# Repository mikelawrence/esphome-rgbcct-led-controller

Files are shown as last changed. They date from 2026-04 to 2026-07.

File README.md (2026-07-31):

# ESPHome RGBCCT LED Controller

<p align="center">
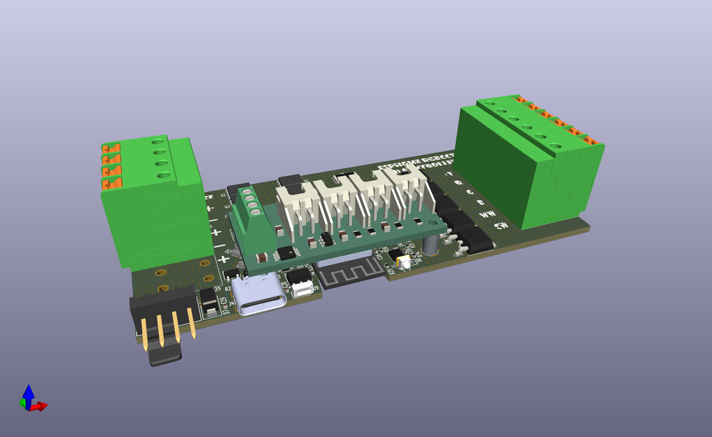
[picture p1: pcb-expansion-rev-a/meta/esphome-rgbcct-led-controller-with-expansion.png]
  
</p>

This project evolved from the need to support LED strips for growing African Violets. It is surprising how much light plants need and how little light LED strip actually put out. My original approach was three strips composed of Cool White (CW) and Warm White LEDs (WW). But it wasn't until I purchased a Photosynthetically Active Radiation (PAR) meter to measure the Photosynthetic Photon Flux Density (PPFD, units µmol/m²/s) just how un-bright my setup was. These units are interesting. The first part, µmol, is a number, specifically one-millionth of a mole, or 6.022 x 10²³ / 1,000,000 or 6.022 x 10¹⁷. The second part is an area, 1 meter squared. And finally time in seconds. When put together it is basically the number of photons striking a one meter squared area per second. Most measurements of light intensity, like lux, lumens, or luminance, are based on human perception are not really good for plants so PAR/PPFD was developed in the 1970s by Dr. Keith McCree. When I measured the light output of my setup with my shiny new PAR meter I got 20PPFD with my original setup of three strips of CW and WW LEDs between 60 and 200PPFD. There is different and sometimes conflicting information on the Internet but the range I found for African Violets is somewhere between 60 and 200PPFD. So my setup was three times less than minimum of 60PPFD.

Clearly I need more light. I started looking on Internet for "brighter" LED strips. I found [these](https://www.superlightingled.com/dc24v-112ledsm-highest-density-5in1-rgbww-led-strip-smd5050-164ft-p-5599.html) from SUPERLIGHTINGLED they have 5 different LEDS, Red, Green, Blue, Warm White and Cool Light. This is five PWM channels which reduces the available controllers to only a few but I did find a Zigbee 5-channel controller. But the control of the LEDs are difficult. What I really needed was to turn on all LEDS simultaneously and this controller could not so this with Home Assistant. It also adjust the light intensity with gamma which again is based on human perception. I found another controller from GLEDOPTO with WLED installed which gave me chance to control everything in the way I wanted and that is when I realized turning all the LEDS on at the same time caused them to warm up to more than 50°C. Not necessarily a problem but one that would probably shorten the life of the strips. I ended up with five of these LED strips per shelf running at a reduced intensity and still have 80PPFD.

Now that the light levels are in better range I decided to design my own LED controller because I wanted to add 4-Pin computer fan control and temperature measurement of both ambient and some of the LED strips to make sure I wasn't getting them too hot.

This LED controller supports the following:

* ESP32-S3
* ESPHome software development
* USB-C Interface for initial/ongoing programming, OTA will still be the primary mean of programming
* Power, Voltage and Current measurement with an INA232
* 5-Channel PWM LED control
* Supporting 5-24V Vin, this same voltage is applied to the LED and fan
* Two configurations: One supporting 5A and with the addition of two transistors 10A total current
* Each channel comfortably supports 2A simultaneous and up to 3-4A singly
* Vin is well protected
  * No damage input range is ±33V, TVS will adsorb higher transients
  * Over current shutdown
  * Over temperature shutdown
  * Short circuit shutdown
  * Reverse Polarity shutdown
  * Over Voltage Lockout
  * Under Voltage Lockout
* PCB temperature measurement near the Vin protection circuit. This is broken.
* Each channel is a protected MOSFET, if will shutdown when over temperature and will take a short to ground without damage
* With the addition of an expansion board
  * LED strip temperature measurement with 10K thermistors.
  * Ambient temperature measurement with a commonly available SHTXX I²C sensor

## Main PCB

<p align="center">
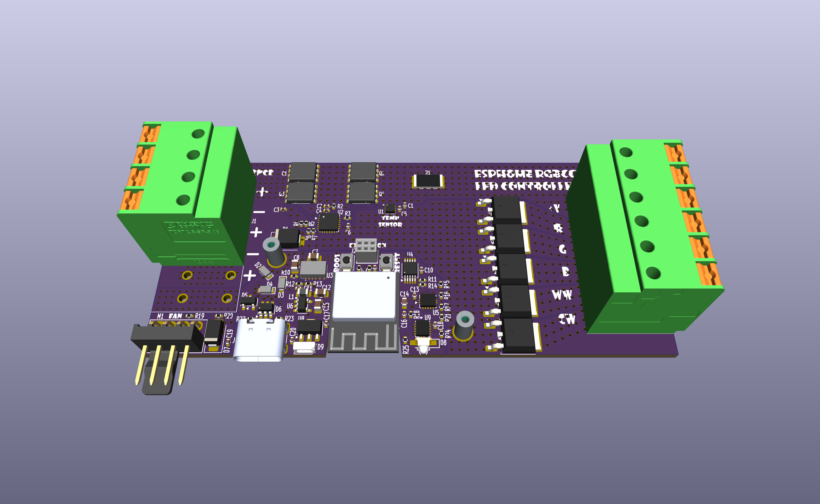
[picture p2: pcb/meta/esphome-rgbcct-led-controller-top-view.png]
  
</p>

View the [README](pcb/README.md) for more information about this PCB.

## Temperature Expansion PCBs

<p align="center">
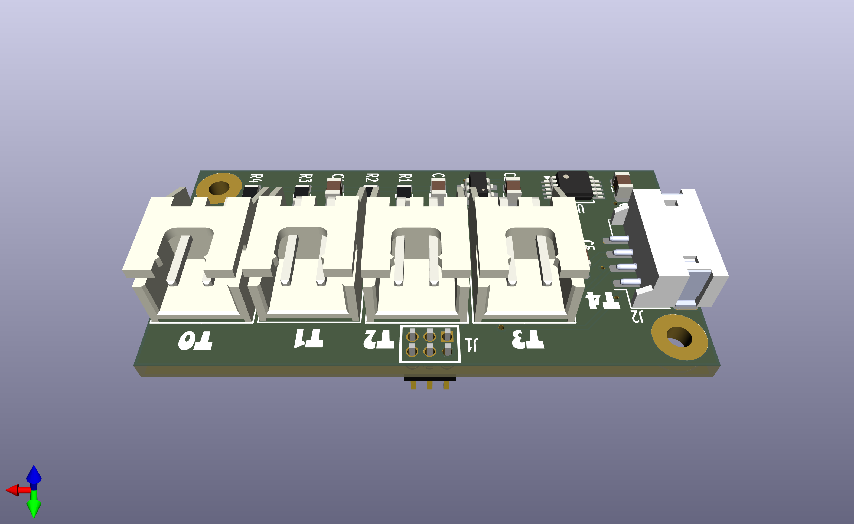
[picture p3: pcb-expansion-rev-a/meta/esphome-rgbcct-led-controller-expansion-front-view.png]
    
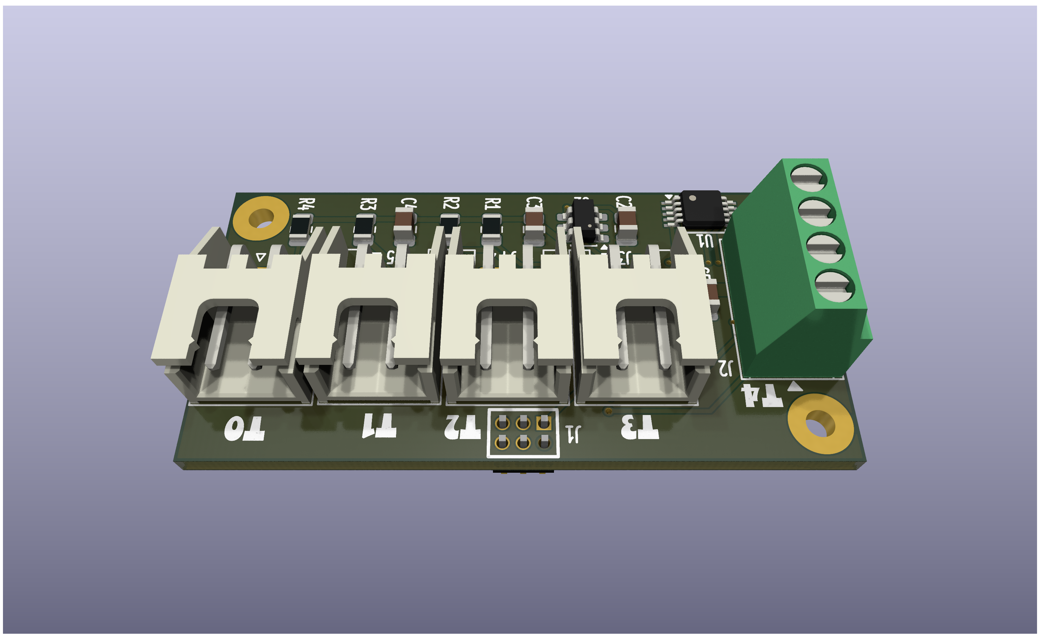
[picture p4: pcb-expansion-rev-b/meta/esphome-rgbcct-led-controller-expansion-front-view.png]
    
</p>

View the [Rev A README](pcb-expansion-rev-a/README.md) or [Rev B README](pcb-expansion-rev-b/README.md) for more information.

## Configuration

[RGBCCT LED Controller GH Pages](https://mikelawrence.github.io/esphome-rgbcct-led-controller/) provides installation and Home Assistant configuration support.

## Web Server

Th Web Server is enabled in the current configuration. The default username is `light` and password is `password`. Auth is enabled mainly because manual firmware updates are enabled in the Web Server.

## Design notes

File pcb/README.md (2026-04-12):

# ESPHome RGBCCT LED Controller PCB

<p align="center">
  
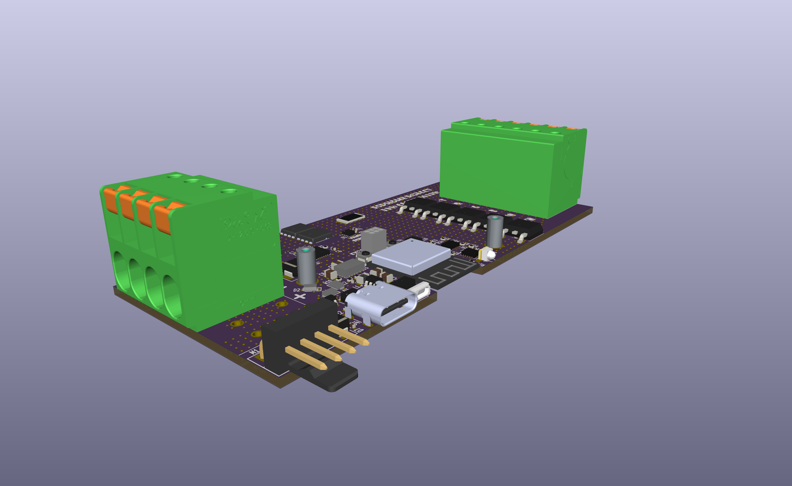
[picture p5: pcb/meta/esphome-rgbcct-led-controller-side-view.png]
  
</p>

The PCB is designed in [KiCad](https://www.kicad.org/). Fabrication and is tuned toward [JCLPCB](https://jlcpcb.com/). I using my [Whizoo Controleo3](https://whizoo.com/) oven to handle all but the Thru-Hole stuff which is hand soldered.

* **Rev A**: Has been fabricated, assembled, tested and is use in four places. There is one issue TMP1075 (U1) is connected to VINP and will burn when powered by 24V and must be left off the PCB.

## Testing Notes

Only the 5A configuration has been tested. Short circuit on LED outputs will not damage the board but the red LED will not light up. This type of short circuits will recover automatically recover when removed. Short circuits on the fan connector will shut off power to everything and cause the red LED to light up. Short circuits of this type are latching and require power-cycling to release. Over-voltage and Under-Voltage Lock Out work fine. The 4-Pin fan connector supports fans but the PWM signal is 1.5kHz well below the recommended 25kHz. There seems to be an issue with the ledc component the prevents different pwm frequencies when using 6 ledc channels. 1.5kHz work well with Noctua fans.

## Schematic

<p align="center">
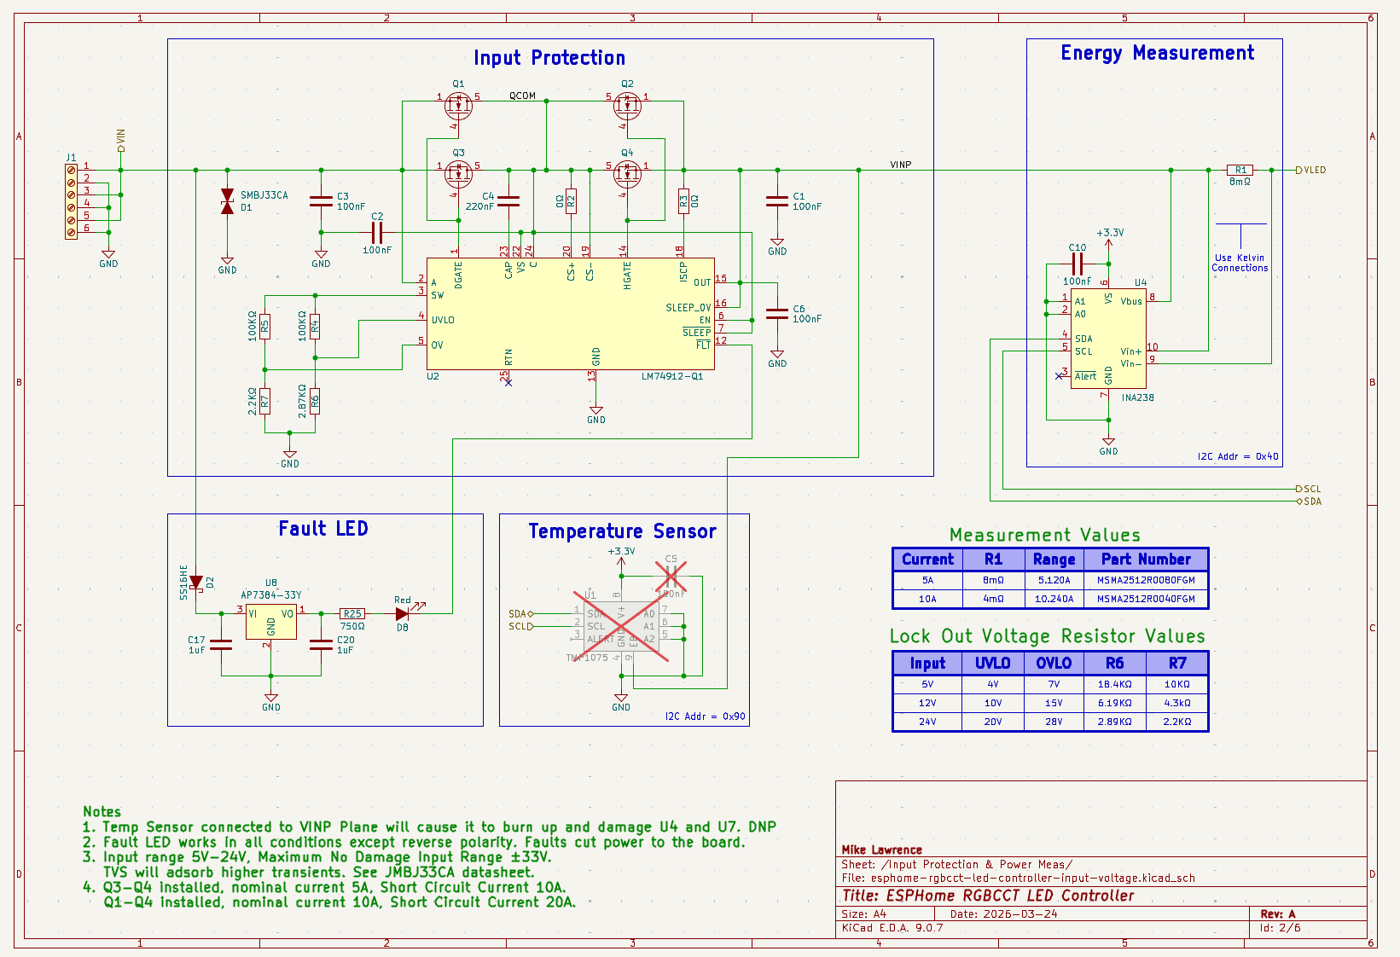
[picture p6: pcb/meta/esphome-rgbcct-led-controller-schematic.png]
     <br />
    Schematic
</p>

### Do Not Populate (DNP) Notes

TMP1075 (U1) cannot be populated due to a PCB error. It will burn with 24V Vin.

## Bill of Materials

<p align="center">
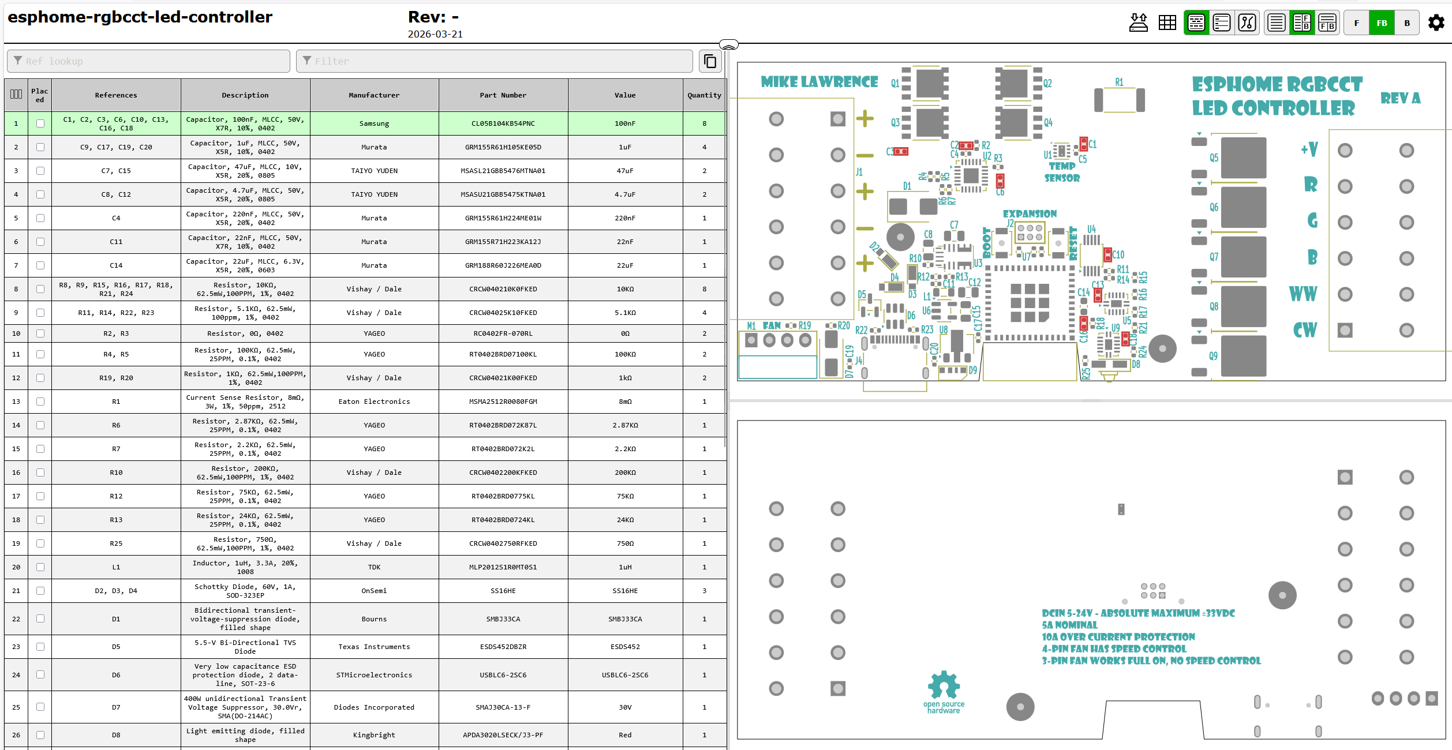
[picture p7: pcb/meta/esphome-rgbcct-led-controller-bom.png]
     <br />
    Interactive BOM
</p>

## PCB Info

* 6 layers with many vias to support high currents. Vias should be filled to improve thermals.
* Two configurations, 5A Continuous, 10A Short Circuit and 10A Continuous and 20A Short Circuit.
* Dimensions are 100mm X 45mm.
* Requires oven reflow or hot air to assemble most components.

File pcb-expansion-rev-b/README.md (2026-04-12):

## ESPHome RGBCCT LED Controller Temperature Expansion PCB Rev B

<p align="center">
  
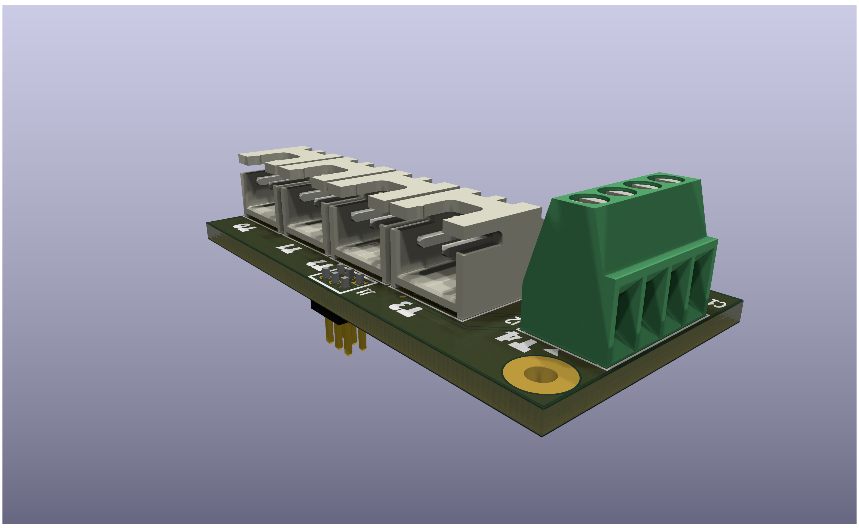
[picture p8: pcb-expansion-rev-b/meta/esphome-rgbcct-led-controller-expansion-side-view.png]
  
</p>

This is a simple expansion board used to add both thermistor measurement and i2c expansion, mainly for off-board temperature and humidity sensors like SHTxxx devices. Rev B has a screw terminal for the off-board i2c temperature/humidity sensor. This PCB is designed in [KiCad](https://www.kicad.org/). Fabrication and is tuned toward [JCLPCB](https://jlcpcb.com/). 100% hand-soldered.

* **Rev B**: Has has not been fabricated nor tested.

## Schematic

<p align="center">
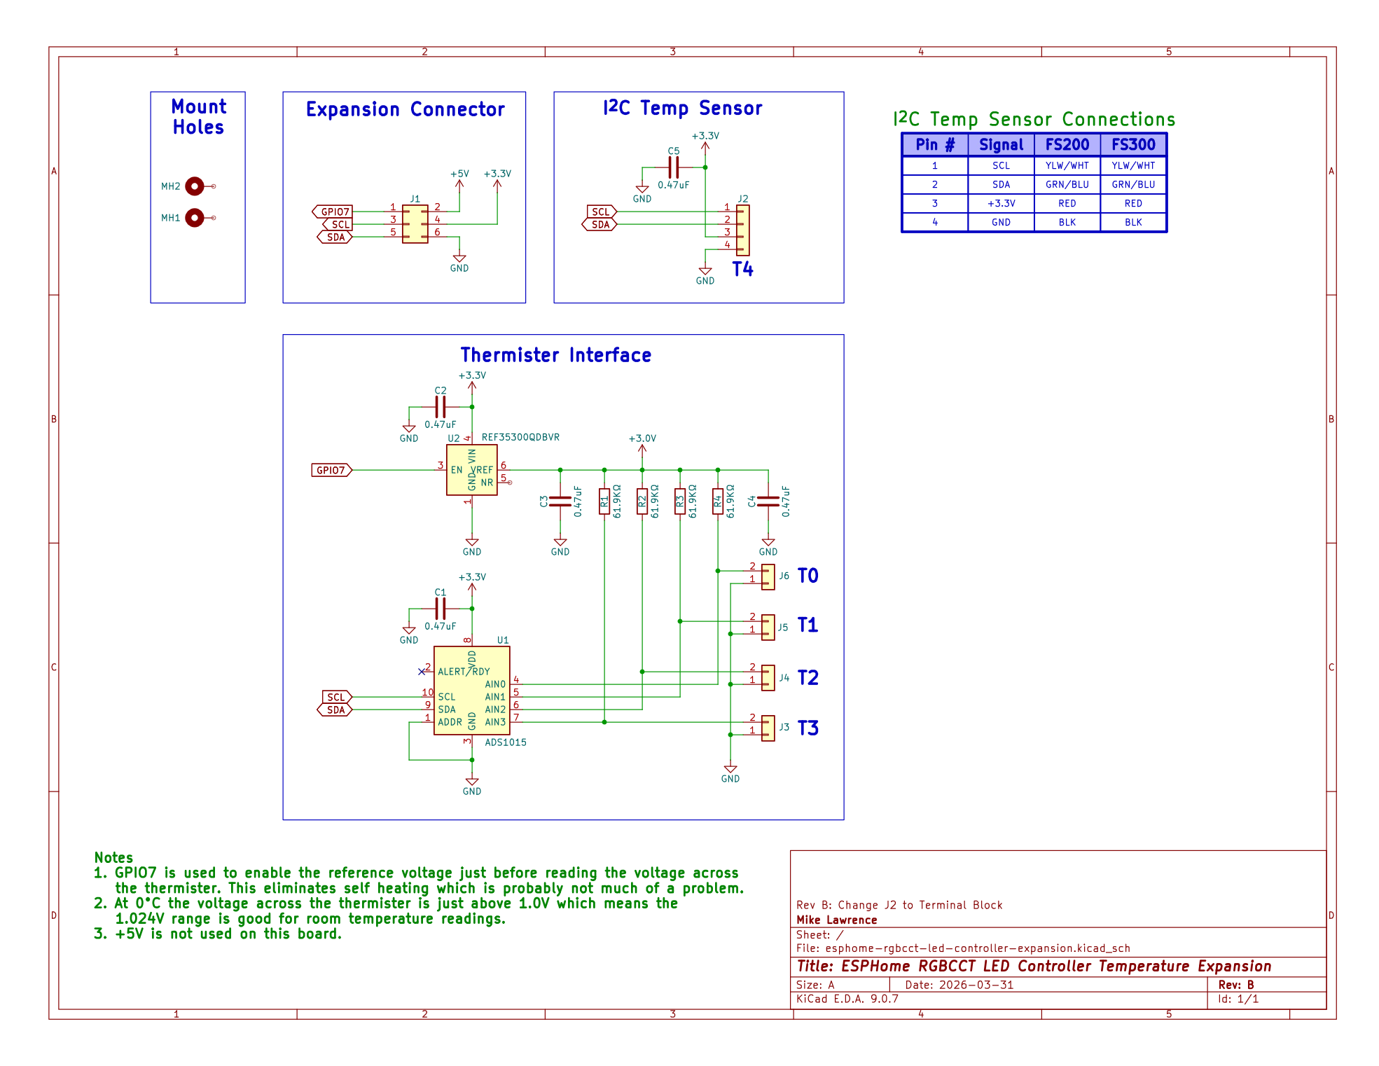
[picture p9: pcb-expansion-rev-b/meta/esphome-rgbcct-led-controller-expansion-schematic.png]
     <br />
    Schematic
</p>

## Bill of Materials

<p align="center">
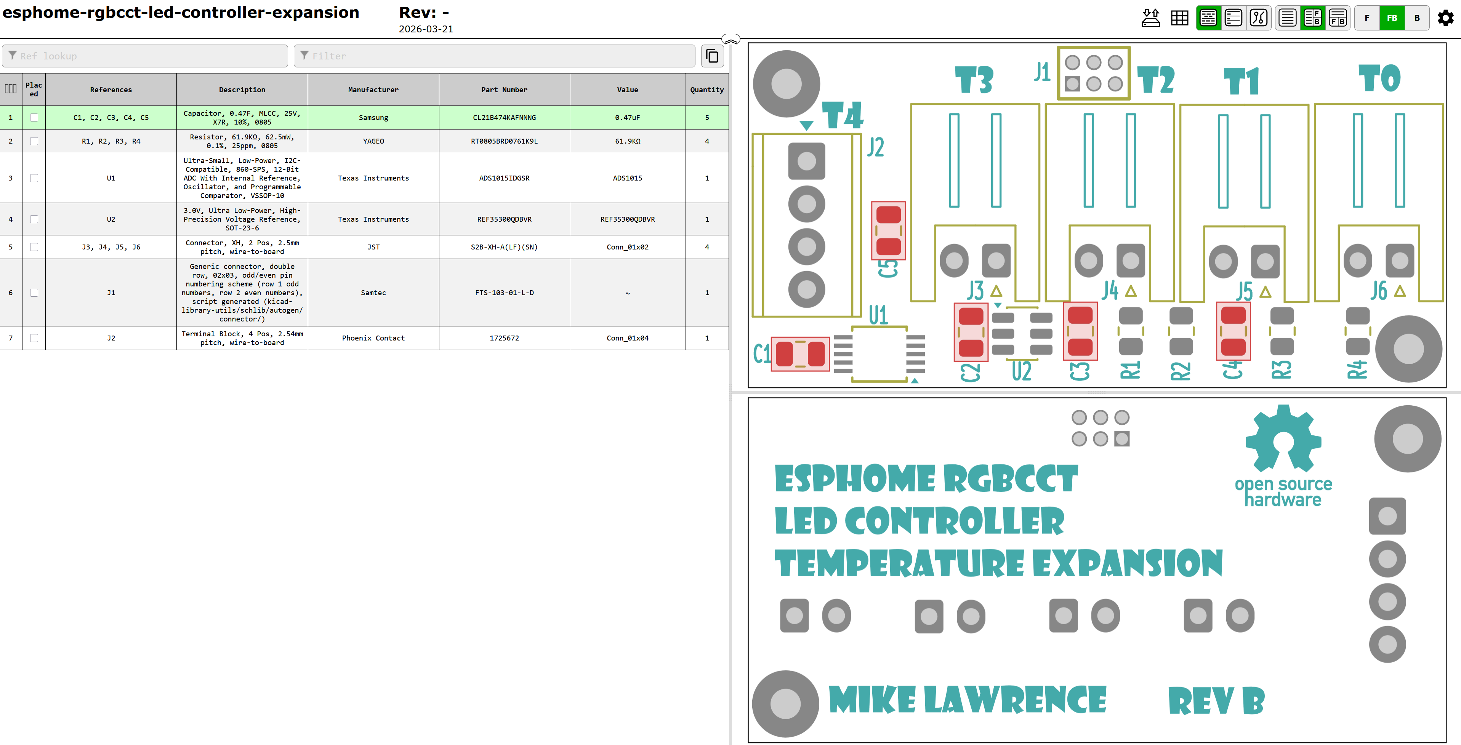
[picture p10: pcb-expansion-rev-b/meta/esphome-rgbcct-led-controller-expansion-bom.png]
     <br />
    Interactive BOM
</p>

## PCB Info

* 2 layers, simple inexpensive PCB.
* Intended for hand-soldering.

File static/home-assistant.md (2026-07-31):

---
description: Using the Multi-Sensor in Home Assistant
---

Sensor

# Home Assistant

There are numerous entities presented to Home Assistant here is a complete list of each with a description.

## Controls

- **Fan** (*Fan*): Provides Fan control in percentage. This is the offboard muffin fan used to circulate air.

- **Light** (*RGBWW Light*): Light control for the LED light strips connected to the controller. Supports 5 channels of PWM for Red, Green, Blue, Warm White and Cool White LED channels.

## Sensors

- **Current** (*Sensor*): This measures the current (A) the entire unit is using including LED lights strips. Updates every minute.

- **Energy** (*Sensor*): This measures the accumulated energy (W Hr) the entire unit has used including LED lights strips. Updates every minute. Resets ant midnight.

- **Fan RPM** (*Sensor*): Current Fan RPM reading. Updates every minute.

- **Humidity** (*Sensor*): Current Humidity sensor reading from the offboard temperature sensor stalk. This is part of a SHT3X sensor. Updates every minute.

- **LED Blue** (*Sensor*): This is the current Blue LED channel intensity in percentage. Updates every change of RGBWW light. Not enabled by default.

- **LED Green** (*Sensor*): This is the current Blue LED channel intensity in percentage. Updates every change of RGBWW light. Not enabled by default.

- **LED Red** (*Sensor*): This is the current Blue LED channel intensity in percentage. Updates every change of RGBWW light. Not enabled by default.

- **LED White Cool** (*Sensor*): This is the current Cool White LED channel intensity in percentage. Updates every change of RGBWW light. Not enabled by default.

- **LED White Warm** (*Sensor*): This is the current Warm White LED channel intensity in percentage. Updates every change of RGBWW light. Not enabled by default.

- **Power** (*Sensor*): This measures the current (A) the entire unit is using including LED lights strips. Updates every minute.

- **Temperature** (*Sensor*): Current Temperature sensor reading from the offboard temperature sensor stalk. This is part of a SHT3X sensor. Updates every minute.

- **Voltage** (*Sensor*): This measures the voltage (V) applied to the unit. Updates every minute.

## Configuration

- **Max Power** (*Number*): Provide the means to limit the total power the RGBWW Light. In some cases a LED Light strip with 5 channels of LED control will
get too hot if all channels are on. By lowering this number from 100% you can effectively limit the total output power. The following equation is used to
determine the brightness level of the RGBWW light.

Brightness = 100 * (RLED(%) + GLED(%) + BLED(%) + WWLED(%) + CW(%)) / (RLED(100%) + GLED(100%) + BLED(100%) + WWLED(100%) + CW(100%))

Adjusting brightness will keep the light color consistent for the most part.

- **Restart** (*Button*): Will restart RGBCCT LED Controller

[back](./)

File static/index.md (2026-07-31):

Sensor

# Web Installation

Use the button below to install pre-built firmware directly to your hardware via USB. You must use Google Chrome or Microsoft Edge to program your device. Firefox does not work.

| &nbsp; &nbsp; &nbsp; &nbsp; &nbsp; 5A Nominal 10A Short &nbsp; &nbsp; &nbsp; &nbsp; &nbsp; | &nbsp; &nbsp; &nbsp; &nbsp; &nbsp; 10A Nominal 20A Short &nbsp; &nbsp; &nbsp; &nbsp; &nbsp; |
| :---: | :---: |
| <esp-web-install-button manifest="firmware/rgbcct-led-controller-5amp.manifest.json"></esp-web-install-button> | <esp-web-install-button manifest="firmware/rgbcct-led-controller-10amp.manifest.json"></esp-web-install-button> |

<script type="module" src="https://unpkg.com/esp-web-tools@10/dist/web/install-button.js?module"></script>

# Configuration Notes

Click [Home Assistant configuration page](./home-assistant.html) to learn what's available in Home Assistant.

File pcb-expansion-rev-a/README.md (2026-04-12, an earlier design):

## ESPHome RGBCCT LED Controller Temperature Expansion PCB Rev A

<p align="center">
  
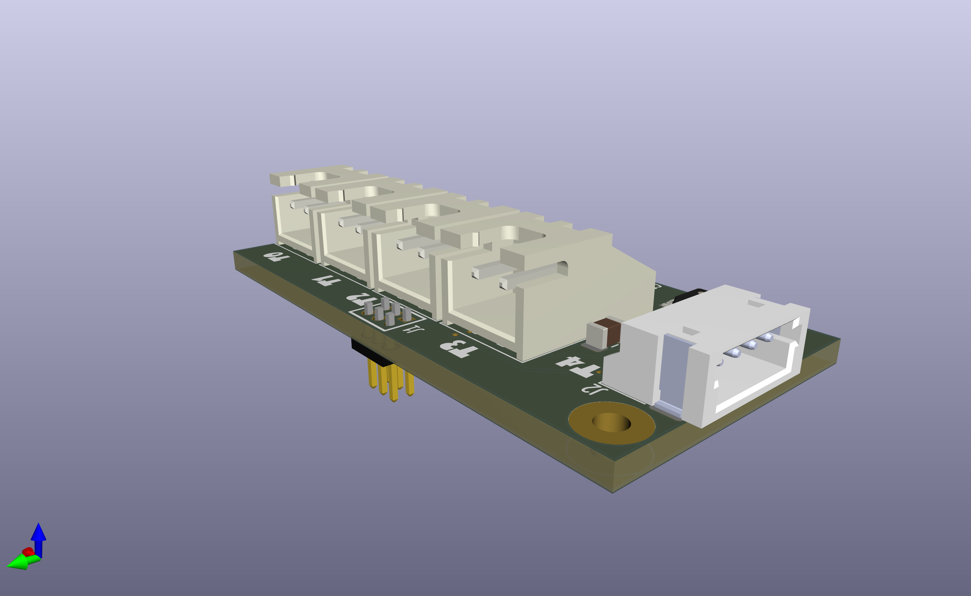
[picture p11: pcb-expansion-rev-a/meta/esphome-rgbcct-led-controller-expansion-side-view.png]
  
</p>

This is a simple expansion board used to add both thermistor measurement and i2c expansion, mainly for off-board temperature and humidity sensors like SHTxxx devices. Rev A has a JST ZR connector for the off-board i2c temperature/humidity sensor. This PCB is also designed in [KiCad](https://www.kicad.org/). Fabrication and is again tuned toward [JCLPCB](https://jlcpcb.com/). 100% hand-soldered.

* **Rev A**: Has has fabricated, assembled and tested. No issues.

## Schematic

<p align="center">
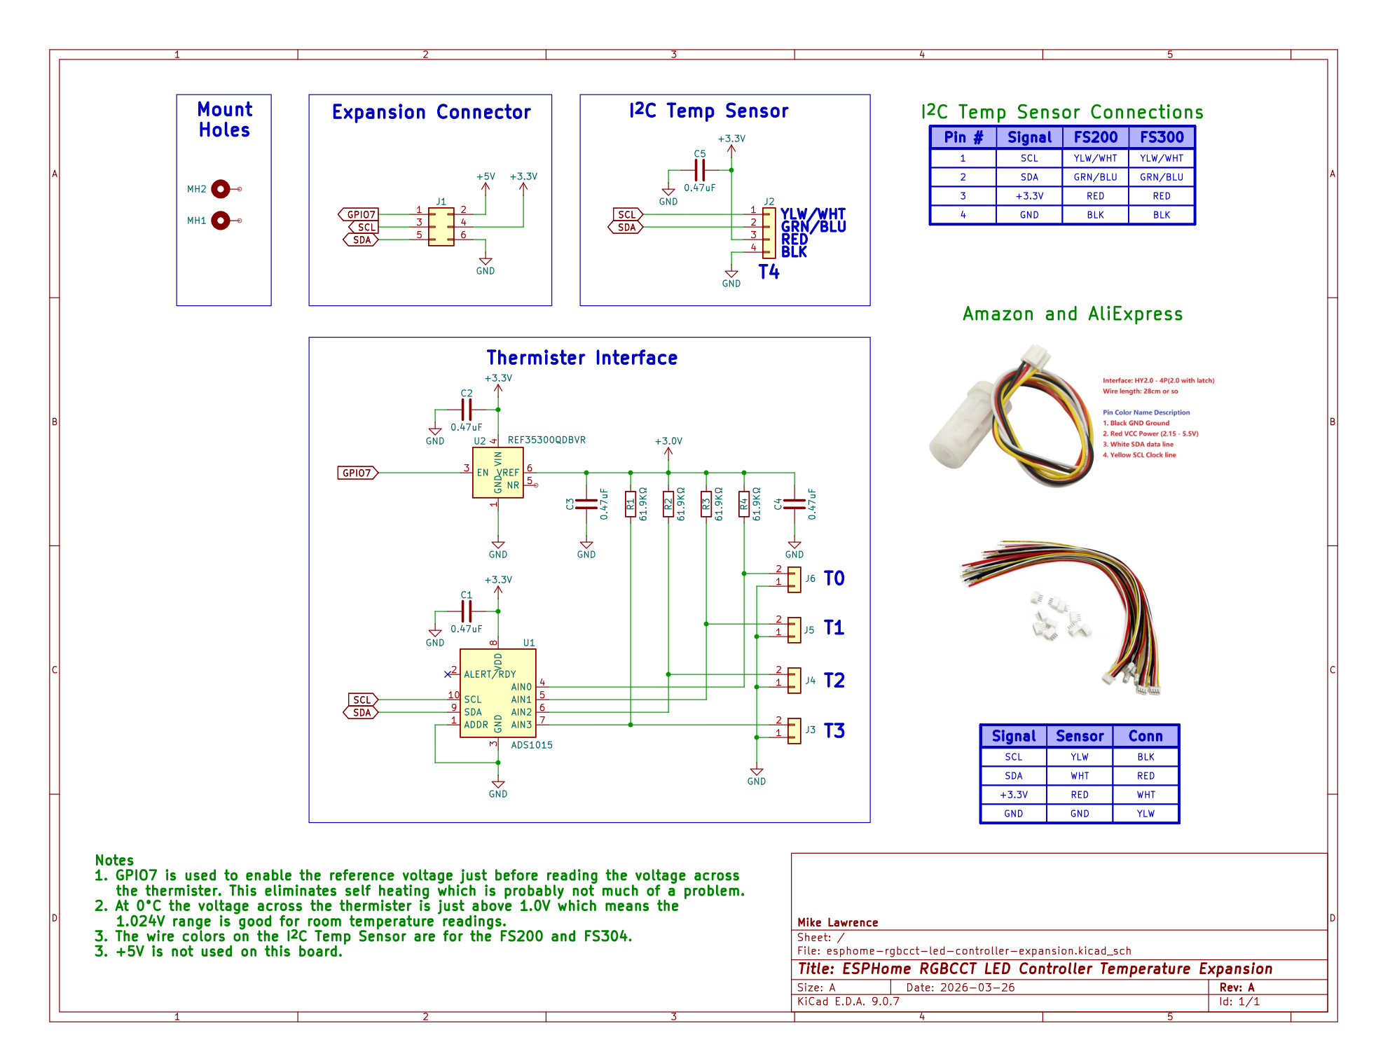
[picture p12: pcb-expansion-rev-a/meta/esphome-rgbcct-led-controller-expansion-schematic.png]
     <br />
    Schematic
</p>

## Bill of Materials

<p align="center">
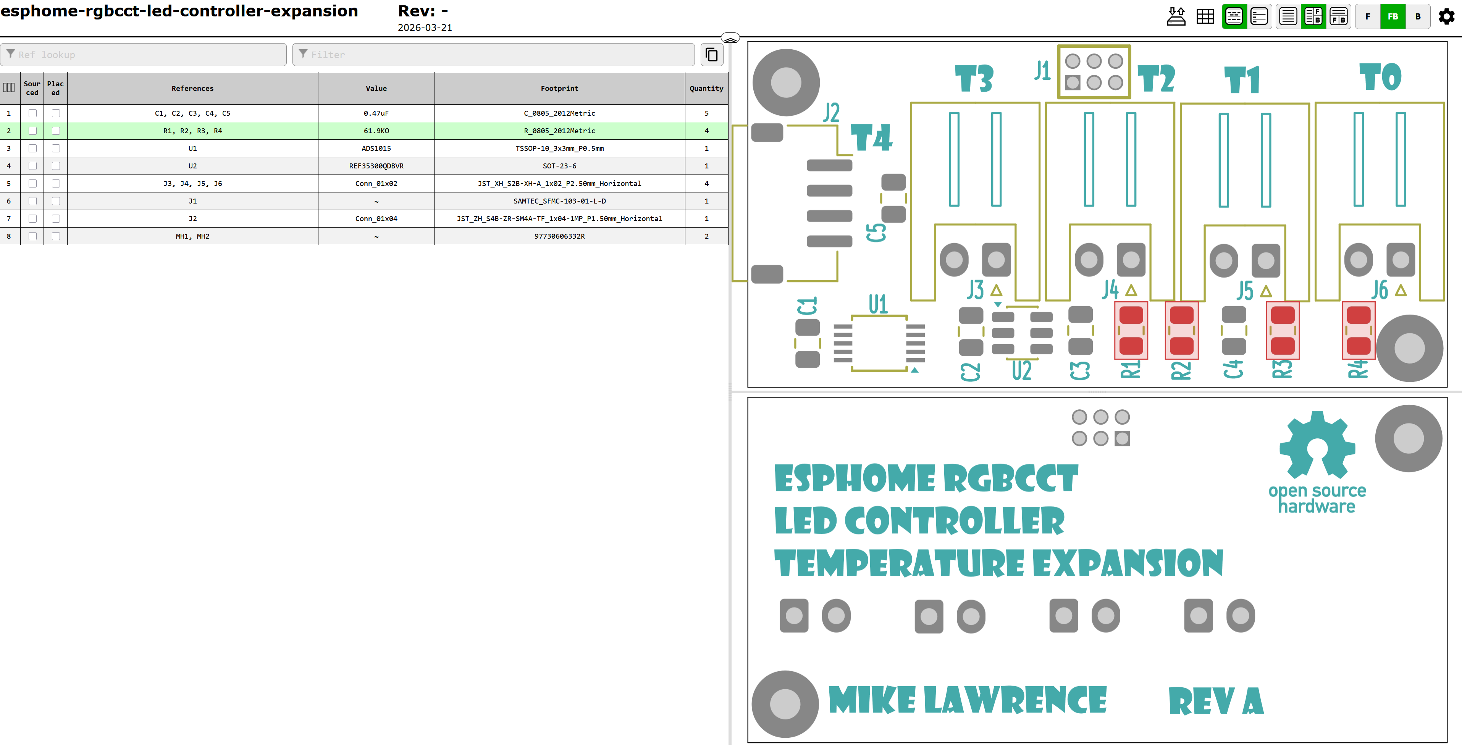
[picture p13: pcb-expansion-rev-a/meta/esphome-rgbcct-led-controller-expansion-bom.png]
     <br />
    Interactive BOM
</p>

## PCB Info

* 2 layers, simple inexpensive PCB.
* Intended for hand-soldering.

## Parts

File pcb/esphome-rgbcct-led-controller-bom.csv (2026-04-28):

Qty | Reference | Value | Description | Datasheet | Footprint | DNP | Manufacturer | Part Number
9 | C1,C2,C3,C5,C6,C10,C13,C16,C18 | 100nF | Capacitor, 100nF, MLCC, 50V, X7R, 10%, 0402 |  | Capacitor_SMD:C_0402_1005Metric | DNP | Samsung | CL05B104KB54PNC
1 | C4 | 220nF | Capacitor, 220nF, MLCC, 50V, X5R, 20%, 0402 |  | Capacitor_SMD:C_0402_1005Metric |  | Murata | GRM155R61H224ME01W
2 | C7,C15 | 47uF | Capacitor, 47uF, MLCC, 10V, X5R, 20%, 0805 |  | Capacitor_SMD:C_0805_2012Metric |  | TAIYO YUDEN | MSASL21GBB5476MTNA01
2 | C8,C12 | 4.7uF | Capacitor, 4.7uF, MLCC, 50V, X5R, 20%, 0805 |  | Capacitor_SMD:C_0805_2012Metric |  | TAIYO YUDEN | MSASU21GBB5475KTNA01
4 | C9,C17,C19,C20 | 1uF | Capacitor, 1uF, MLCC, 50V, X5R, 10%, 0402 |  | Capacitor_SMD:C_0402_1005Metric |  | Murata | GRM155R61H105KE05D
1 | C11 | 22nF | Capacitor, 22nF, MLCC, 50V, X7R, 10%, 0402 |  | Capacitor_SMD:C_0402_1005Metric |  | Murata | GRM155R71H223KA12J
1 | C14 | 22uF | Capacitor, 22uF, MLCC, 6.3V, X5R, 20%, 0603 |  | Capacitor_SMD:C_0603_1608Metric |  | Murata | GRM188R60J226MEA0D
1 | D1 | SMBJ33CA | Bidirectional transient-voltage-suppression diode, filled shape |  | Diode_SMD:D_SMB |  | Bourns | SMBJ33CA
3 | D2,D3,D4 | SS16HE | Schottky Diode, 60V, 1A, SOD-323EP | https://www.onsemi.com/pdf/datasheet/ss13he-d.pdf | SS16HE:SS16HE |  | OnSemi | SS16HE
1 | D5 | ESDS452 | 5.5-V Bi-Directional TVS Diode | https://www.ti.com/lit/ds/symlink/esds452.pdf | Package_TO_SOT_SMD:SOT-23 |  | Texas Instruments | ESDS452DBZR
1 | D6 | USBLC6-2SC6 | Very low capacitance ESD protection diode, 2 data-line, SOT-23-6 | https://www.st.com/resource/en/datasheet/usblc6-2.pdf | Package_TO_SOT_SMD:SOT-23-6 |  | STMicroelectronics | USBLC6-2SC6
1 | D7 | 30V | 400W unidirectional Transient Voltage Suppressor, 30.0Vr, SMA(DO-214AC) | https://www.littelfuse.com/media?itemid=75e32973-b177-4ee3-a0ff-cedaf1abdb93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 | Diode_SMD:D_SMA |  | Diodes Incorporated | SMAJ30CA-13-F
1 | D8 | Red | Light emitting diode, filled shape | https://www.kingbrightusa.com/images/catalog/SPEC/APDA3020LSECK-J3-PF.pdf | APDA3020LSECK_J3-PF:APDA3020LSECKJ3PF |  | Kingbright | APDA3020LSECK/J3-PF
1 | D9 | SK6812-4020 | RGB LED with integrated controller, 4mm x 2mm Side LED package | https://cdn-shop.adafruit.com/product-files/4691/4691_SK68XX_SIDE_REV.04_EN_1_.pdf | SK6812-4020:SK6812-4020 |  | Adafruit | 4691
1 | J1 | 1017505 | Terminal Block, 12-24 AWG, push-in connection, 4-position, 32A | https://www.mouser.com/datasheet/3/507/10/phoenix_contact_1017507_en.pdf | 1017507:1017507 |  | Phoenix Contact | 1017505
1 | J2 |  | Generic connector, double row, 02x03, odd/even pin numbering scheme (row 1 odd numbers, row 2 even numbers), script generated (kicad-library-utils/schlib/autogen/connector/) |  | SAMTEC_SFMC10301LD:SAMTEC_SFMC-103-01-L-D |  | Samtec | SFMC-103-01-L-D
1 | J3 | 1017507 | Terminal Block, 12-24 AWG, push-in connection, 6-position, 32A | https://www.mouser.com/datasheet/3/507/10/phoenix_contact_1017507_en.pdf | 1017507:1017507 |  | Phoenix Contact | 1017507
1 | J4 | USB-C | Connector, USB 2.0, 16P, Type-C, Receptacle | https://www.usb.org/sites/default/files/documents/usb_type-c.zip | TYPE-C-31-M-12:HRO_TYPE-C-31-M-12 |  | Phoenix Contact | 1332645
1 | L1 | 1uH | Inductor, 1uH, 3.3A, 20%, 1008 |  | Inductor_SMD:L_0805_2012Metric |  | TDK | MLP2012S1R0MT0S1
1 | M1 | Fan_CPU_4pin | CPU Fan, tacho output, PWM input, 4-pin connector | http://www.formfactors.org/developer%5Cspecs%5Crev1_2_public.pdf | Connector:FanPinHeader_1x04_P2.54mm_Vertical |  | Molex | 47053-1000
2 | MH1,MH2 |  | Mounting Hole with connection | https://www.we-online.com/components/products/datasheet/97730606332R.pdf | 97730606332R:97730606332R |  | Wurth | 97730606332R
4 | Q1,Q2,Q3,Q4 | TQM050NB06CR | N-MOSFET transistor, 60V, 104A, 5mΩ, 3.8V Vgs, PDFN56U | https://services.taiwansemi.com/storage/resources/datasheet/TQM050NB06CR_A2003.pdf | TQM050NB06CR_RLG:TRANS_TQM050NB06CR_RLG |  | Taiwan Semiconductor | TQM050NB06CR RLG
5 | Q5,Q6,Q7,Q8,Q9 | NCV8411 | Self-Protected Low Side Driver with Temperature and Current Limit, TO-252-2 | https://www.onsemi.com/pdf/datasheet/ncv8411-d.pdf | Package_TO_SOT_SMD:TO-252-2 |  | OnSemi | NCV8411DTRKG
1 | R1 | 8mΩ | Current Sense Resistor, 8mΩ, 3W, 1%, 50ppm, 2512 |  | Resistor_SMD:R_2512_6332Metric |  | Eaton Electronics | MSMA2512R0080FGM
2 | R2,R3 | 0Ω | Resistor, 0Ω, 0402 |  | Resistor_SMD:R_0402_1005Metric |  | YAGEO | RC0402FR-070RL
2 | R4,R5 | 100KΩ | Resistor, 100KΩ, 62.5mW, 25PPM, 0.1%, 0402 |  | Resistor_SMD:R_0402_1005Metric |  | YAGEO | RT0402BRD07100KL
1 | R6 | 2.87KΩ | Resistor, 2.87KΩ, 62.5mW, 25PPM, 0.1%, 0402 |  | Resistor_SMD:R_0402_1005Metric |  | YAGEO | RT0402BRD072K87L
1 | R7 | 2.2KΩ | Resistor, 2.2KΩ, 62.5mW, 25PPM, 0.1%, 0402 |  | Resistor_SMD:R_0402_1005Metric |  | YAGEO | RT0402BRD072K2L
8 | R8,R9,R15,R16,R17,R18,R21,R24 | 10KΩ | Resistor, 10KΩ, 62.5mW,100PPM, 1%, 0402 |  | Resistor_SMD:R_0402_1005Metric |  | Vishay / Dale | CRCW040210K0FKED
1 | R10 | 200KΩ | Resistor, 200KΩ, 62.5mW,100PPM, 1%, 0402 |  | Resistor_SMD:R_0402_1005Metric |  | Vishay / Dale | CRCW0402200KFKED
4 | R11,R14,R22,R23 | 5.1KΩ | Resistor, 5.1KΩ, 62.5mW, 100ppm, 1%, 0402 |  | Resistor_SMD:R_0402_1005Metric |  | Vishay / Dale | CRCW04025K10FKED
1 | R12 | 75KΩ | Resistor, 75KΩ, 62.5mW, 25PPM, 0.1%, 0402 |  | Resistor_SMD:R_0402_1005Metric |  | YAGEO | RT0402BRD0775KL
1 | R13 | 24KΩ | Resistor, 24KΩ, 62.5mW, 25PPM, 0.1%, 0402 |  | Resistor_SMD:R_0402_1005Metric |  | YAGEO | RT0402BRD0724KL
2 | R19,R20 | 1kΩ | Resistor, 1KΩ, 62.5mW,100PPM, 1%, 0402 |  | Resistor_SMD:R_0402_1005Metric |  | Vishay / Dale | CRCW04021K00FKED
1 | R25 | 750Ω | Resistor, 750Ω, 62.5mW,100PPM, 1%, 0402 |  | Resistor_SMD:R_0402_1005Metric |  | Vishay / Dale | CRCW0402750RFKED
2 | SW1,SW2 |  | Switch, SMD | https://omronfs.omron.com/en_US/ecb/products/pdf/en-b3u.pdf | Button_Switch_SMD:SW_SPST_B3U-1000P-B |  | Omron | B3U-1000P
1 | U1 | TMP1075 | I2C-bus digital temperature sensor and thermal watchdog, WSON-8 | https://www.ti.com/lit/gpn/tmp1075 | Package_SON:WSON-8-1EP_2x2mm_P0.5mm_EP0.9x1.6mm_ThermalVias | DNP | Texas Instruments | TMP1075DSGR
1 | U2 | LM74912-Q1 | Automotive Ideal Diode Controller With Fault Output and Overvoltage, Undervoltage, and Short Circuit Protection, VQFN-24 | https://www.ti.com/lit/ds/symlink/lm74912-q1.pdf | Package_DFN_QFN:Texas_RGE0024C_VQFN-24-1EP_4x4mm_P0.5mm_EP2.1x2.1mm |  | Texas Instruments | LM74912QRGERQ1
1 | U3 | MPM3506AGQV-P | Switching Voltage Regulators 36V/0.6A Module Sync Step-Down Converter | https://www.monolithicpower.com/pub/media/document/MPM3506A_r1.0.pdf | MPM3506A:QFN-19 |  | Monolithic Power Systems | MPM3506AGQV-P
1 | U4 | INA238 | IC, 85-V, 16-Bit, High-Precision Power Monitor With I2C Interface, VSSOP-10 | https://www.ti.com/lit/ds/symlink/ina238.pdf | Package_SO:VSSOP-10_3x3mm_P0.5mm |  | Texas Instruments | INA238AIDGSR
2 | U5,U9 | 74AHCT32 | Quad 2-input OR | https://www.ti.com/lit/ds/symlink/sn74ahct32.pdf | Package_DFN_QFN:DHWQFN-14-1EP_2.5x3mm_P0.5mm_EP1x1.5mm |  | Texas Instruments | SN74AHCT32BQAR
1 | U6 | TPS613222ADBV | 1.8A Step-Up Converter, 5V Output Voltage, 0.9-5.5V Input Voltage, SOT-23-5 | http://www.ti.com/lit/ds/symlink/tps61322.pdf | Package_TO_SOT_SMD:SOT-23-5 |  | Texas Instruments | TPS613222ADBVR
1 | U7 | ESP32-C3-MINI-1 | RF Module, ESP32-C3 SoC, Wi-Fi 802.11b/g/n, Bluetooth 5, BLE, 32-bit, 3.3V, onboard antenna, SMD | https://documentation.espressif.com/esp32-c3-mini-1_datasheet_en.pdf | ESP32-C3-MINI:ESP32-C3-MINI-1-N4X |  | Espressif Systems | ESP32-C3-MINI-1-N4X
1 | U8 | AP7384-33Y | 50mA Low Dropout Voltage Regulator, Fixed Output 3.3V, Wide Input Voltage Range 40V, SOT-89-3 | https://www.diodes.com/assets/Datasheets/AP7384.pdf | Package_TO_SOT_SMD:SOT-89-3 |  | Diodes Inc | AP7384-33Y-13

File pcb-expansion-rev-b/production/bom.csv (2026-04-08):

Designator | Footprint | Quantity | Value | LCSC Part #
C1, C2, C3, C4, C5 | 0805 | 5 | 0.47uF | C307331
J1 | SAMTEC_SFMC-103-01-L-D | 1 | ~
J2 | TerminalBlock_Phoenix_MPT-0,5-4-2.54_1x04_P2.54mm_Horizontal | 1 | Conn_01x04
J3, J4, J5, J6 | JST_XH_S2B-XH-A_1x02_P2.50mm_Horizontal | 4 | Conn_01x02 | C157931
MH1, MH2 | 97730606332R | 2 | ~
R1, R2, R3, R4 | 0805 | 4 | 61.9KΩ | C136977
U1 | TSSOP-10_3x3mm_P0.5mm | 1 | ADS1015
U2 | SOT-23-6 | 1 | REF35300QDBVR | C6643299

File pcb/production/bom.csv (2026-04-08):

Designator | Footprint | Quantity | Value | LCSC Part #
C1, C10, C13, C16, C18, C2, C3, C5, C6 | 0402 | 9 | 100nF
C11 | 0402 | 1 | 22nF
C12, C8 | 0805 | 2 | 4.7uF
C14 | 0603 | 1 | 22uF
C15, C7 | 0805 | 2 | 47uF
C17, C19, C20, C9 | 0402 | 4 | 1uF
C4 | 0402 | 1 | 220nF
D1 | D_SMB | 1 | SMBJ33CA
D2, D3, D4 | SS16HE | 3 | SS16HE
D5 | SOT-23 | 1 | ESDS452
D6 | SOT-23-6 | 1 | USBLC6-2SC6
D7 | D_SMA | 1 | 30V
D8 | APDA3020LSECKJ3PF | 1 | Red
D9 | SK6812-4020 | 1 | SK6812-4020
J1 | 1017507 | 1 | 1017505
J2 | SAMTEC_SFMC-103-01-L-D | 1 | ~
J3 | 1017507 | 1 | 1017507
J4 | HRO_TYPE-C-31-M-12 | 1 | USB-C
L1 | 0805 | 1 | 1uH
M1 | FanPinHeader_1x04_P2.54mm_Vertical | 1 | Fan_CPU_4pin
MH1, MH2 | 97730606332R | 2 | ~
Q1, Q2, Q3, Q4 | TRANS_TQM050NB06CR_RLG | 4 | TQM050NB06CR
Q5, Q6, Q7, Q8, Q9 | TO-252-2 | 5 | NCV8411
R1 | 2512 | 1 | 8mΩ
R10 | 0402 | 1 | 200KΩ
R11, R14, R22, R23 | 0402 | 4 | 5.1KΩ
R12 | 0402 | 1 | 75KΩ
R13 | 0402 | 1 | 24KΩ
R15, R16, R17, R18, R21, R24, R8, R9 | 0402 | 8 | 10KΩ
R19, R20 | 0402 | 2 | 1kΩ
R2, R3 | 0402 | 2 | 0Ω
R25 | 0402 | 1 | 750Ω
R4, R5 | 0402 | 2 | 100KΩ
R6 | 0402 | 1 | 2.87KΩ
R7 | 0402 | 1 | 2.2KΩ
SW1, SW2 | SW_SPST_B3U-1000P-B | 2 | ~
U1 | WSON-8-1EP_2x2mm_P0.5mm_EP0.9x1.6mm_ThermalVias | 1 | TMP1075
U2 | Texas_RGE0024C_VQFN-24-1EP_4x4mm_P0.5mm_EP2.1x2.1mm | 1 | LM74912-Q1
U3 | QFN-19 | 1 | MPM3506AGQV-P
U4 | VSSOP-10_3x3mm_P0.5mm | 1 | INA238
U5, U9 | DHWQFN-14-1EP_2.5x3mm_P0.5mm_EP1x1.5mm | 2 | 74AHCT32
U6 | SOT-23-5 | 1 | TPS613222ADBV
U7 | ESP32-C3-MINI-1-N4X | 1 | ESP32-C3-MINI-1
U8 | SOT-89-3 | 1 | AP7384-33Y

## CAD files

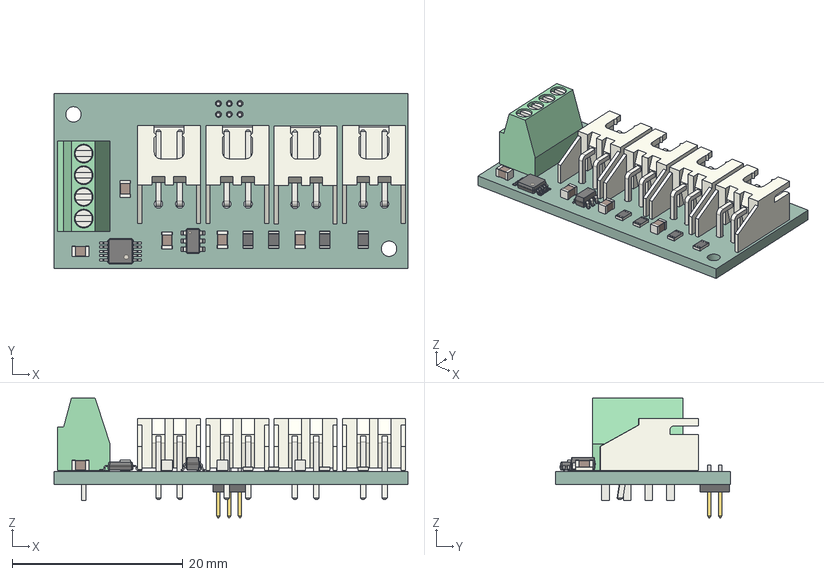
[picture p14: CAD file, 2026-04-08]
pcb-expansion-rev-b/meta/esphome-rgbcct-led-controller-expansion-3d-model.step
41.5 x 20.5 x 14.0 mm
R_0805_2012Metric x 4
JST_XH_S2B-XH-A_1x02_P2.50mm_Horizontal x 4
C_0805_2012Metric x 5
TerminalBlock_Phoenix_MPT-0,5-4-2.54_1x04_P2.54mm_Horizontal
TSSOP-10_3x3mm_P0.5mm
FTS-103-01-L-D_body
FTS-103-01-L-D_pins1
FTS-103-01-L-D_pins2
SOT-23-6
esphome-rgbcct-led-controller-expansion_PCB

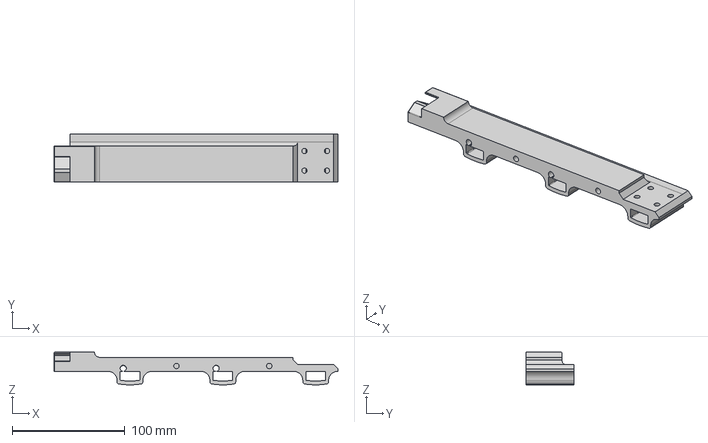
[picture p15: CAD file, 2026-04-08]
pcb/meta/Shelf Light Hanger Left Front.step
252.3 x 42.5 x 28.9 mm

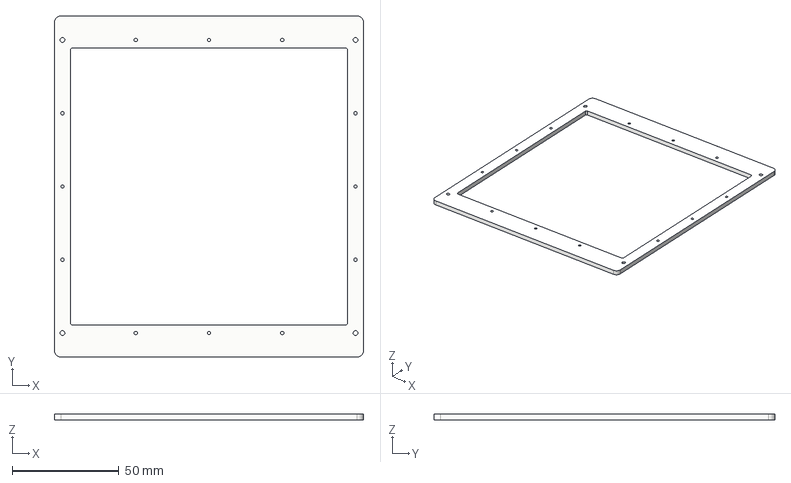
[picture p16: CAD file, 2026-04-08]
pcb/stencil/ESPHome LED RGBCCT LED Controller Stencil Frame.step
145.0 x 160.0 x 2.85 mm

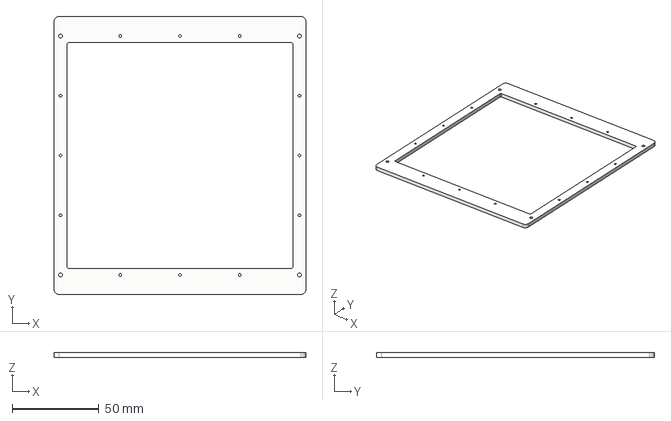
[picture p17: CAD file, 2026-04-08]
pcb/stencil/ESPHome LED RGBCCT LED Controller Stencil Frame Thicker.step
145.0 x 160.0 x 3.00 mm

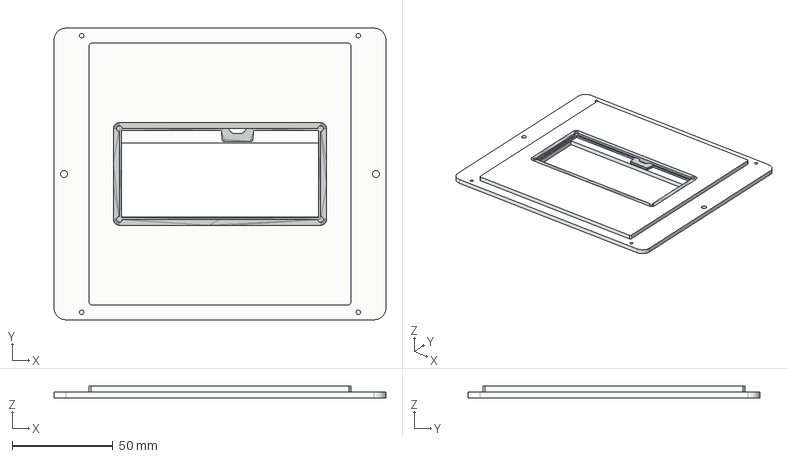
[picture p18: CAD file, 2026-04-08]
pcb/stencil/ESPHome LED RGBCCT LED Controller Stencil Base.step
165.0 x 145.0 x 5.85 mm

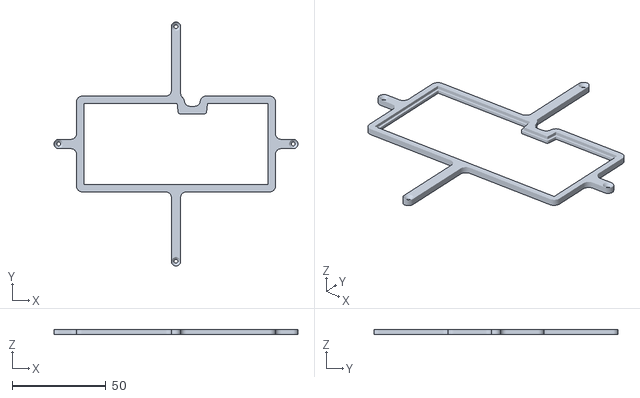
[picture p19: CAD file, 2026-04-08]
pcb/stencil/topRegister.stl
130.0 x 130.0 x 2.85

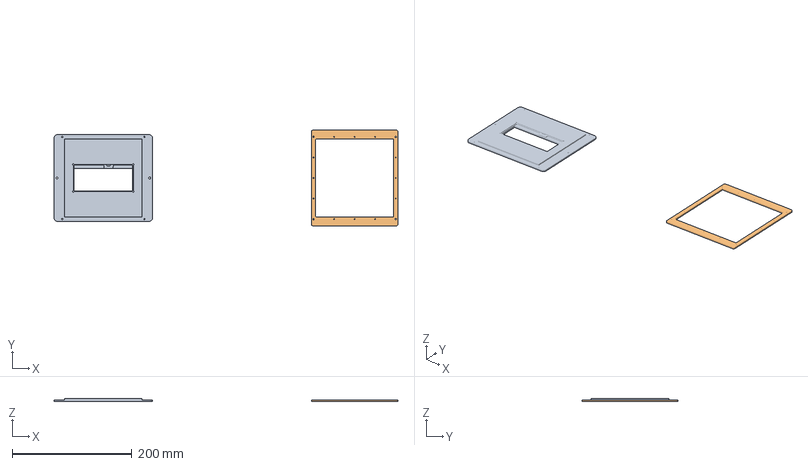
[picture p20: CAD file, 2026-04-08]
pcb/stencil/ESPHome LED RGBCCT LED Controller Stencil Jig.3mf
575.0 x 160.0 x 5.85 mm
ESPHome LED RGBCCT LED Controller Stencil Base.step
ESPHome LED RGBCCT LED Controller Stencil Frame.step

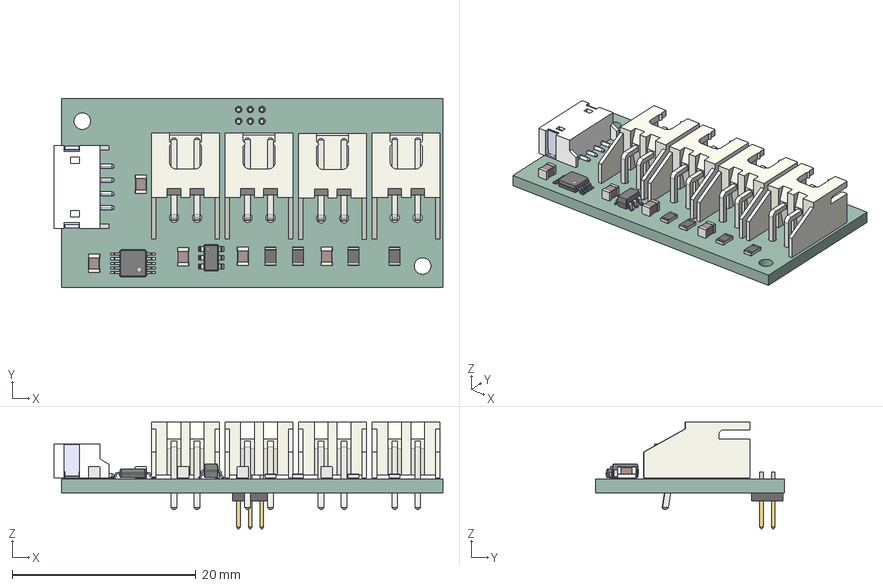
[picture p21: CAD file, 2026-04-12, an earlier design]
pcb-expansion-rev-a/meta/esphome-rgbcct-led-controller-expansion-3d-model.step
42.3 x 20.5 x 11.6 mm
R_0805_2012Metric x 4
JST_XH_S2B-XH-A_1x02_P2.50mm_Horizontal x 4
C_0805_2012Metric x 5
SxB-ZR-SM4A White_4
TSSOP-10_3x3mm_P0.5mm
FTS-103-01-L-D_body
FTS-103-01-L-D_pins1
FTS-103-01-L-D_pins2
SOT-23-6
esphome-rgbcct-led-controller-expansion_PCB

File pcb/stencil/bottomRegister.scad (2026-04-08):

// Generated by SolidPython 1.1.3 on 2026-03-23 19:39:11


scale(v = 0.0000010000) {
	translate(v = [-173250000, -65150000, 0]) {
		difference() {
			linear_extrude(convexity = 10, height = 2850000) {
				polygon(points = [[169751088.2526753247, 89882274.4174628854], [169859119.8252105117, 89983888.5447175354], [169961987.5071879923, 90090709.9987348914], [170059448.7703478336, 90202486.0481248945], [170151265.2974645793, 90318943.3724204749], [170237212.5741086602, 90439797.2042649090], [170317080.4376384914, 90564752.0257367939], [170390673.5911027491, 90693502.2909681052], [170457812.0807889402, 90825733.1732783020], [170518331.7362561822, 90961121.3350059092], [170572084.5717729926, 91099335.7181504071], [170618939.1481783390, 91240038.3538883775], [170658780.8942858279, 91382885.1889993101], [170691512.3870360255, 91527526.9271531701], [170717053.5897226334, 91673609.8830349147], [170735342.0477012396, 91820776.8471907824], [170746333.0411063433, 91968667.9594922662], [170750000.0000000000, 92116933.9533492625], [170750000.0000000000, 127614031.9769262373], [170750000.3036504984, 127614056.6185331643], [170751820.4389982820, 127687898.5018143207], [170751821.3497653604, 127687923.1284563839], [170760227.9659038186, 127858345.4017978758], [170760229.4721206725, 127858369.8483167142], [170762931.8570906222, 127894930.1312516332], [170762936.6630683839, 127894978.8769856691], [170767426.0676938593, 127931362.9726718068], [170767429.3645716906, 127931387.2426443994], [170792634.5663088858, 128101306.9105247408], [170792638.4651764631, 128101331.1419390440], [170798918.7561804354, 128137525.3508284241], [170798928.3316927850, 128137573.4901798218], [170806977.0234656632, 128173415.9422863722], [170806982.6943425238, 128173439.8212261200], [170848703.2653188705, 128339997.6769503355], [170848709.5205062628, 128340021.4095278978], [170858507.2230444551, 128375425.7572444677], [170858521.4709296525, 128375472.7262274027], [170870044.5807096362, 128410353.6773795038], [170870052.5648250580, 128410376.8854924887], [170927897.7645662725, 128572043.3885565102], [170927906.3158326149, 128572066.3937396556], [170941127.0726736188, 128606339.9170606583], [170941145.8557167649, 128606385.2633381337], [170956032.4096572995, 128639968.7909077853], [170956042.6301198602, 128639991.1046872139], [171029455.3777306974, 128795209.3182898760], [171029466.1427226365, 128795231.3745260984], [171045982.6307509840, 128828044.0006862283], [171046005.7680610716, 128828087.2875487953], [171064112.4005101323, 128860049.9638074636], [171064124.7588912249, 128860071.1683594286], [171152398.0494818389, 129007346.2562550604], [171152410.9245266020, 129007367.1511307508], [171172064.0809327066, 129038402.8766010851], [171172091.3496848047, 129038443.6871726215], [171193243.6838739216, 129068477.6940754205], [171193258.0611555874, 129068497.5851884931], [171295541.7746814787, 129206411.2077700049], [171295556.6357853413, 129206430.7400560975], [171318157.1899304986, 129235390.6738362759], [171318188.3275116086, 129235428.6150886416], [171342182.6548990607, 129263244.7087302655], [171342198.9126202166, 129263263.0948421657], [171457508.0010069609, 129390487.0685337633], [171457524.7050493658, 129390505.0501236469], [171482855.0012417734, 129417110.2922194898], [171482889.7077799737, 129417144.9987577051], [171509494.9498772323, 129442475.2949514389], [171509512.9314671457, 129442491.9989938438], [171636736.9051579535, 129557801.0873798728], [171636755.2912698388, 129557817.3451010287], [171664571.3849112988, 129581811.6724883765], [171664609.3261636794, 129581842.8100694865], [171693569.2599435449, 129604443.3642143458], [171693588.7922296226, 129604458.2253182083], [171831502.4148117304, 129706741.9388445914], [171831522.3059248030, 129706756.3161262572], [171861556.3128271997, 129727908.6503151059], [171861597.1233987212, 129727935.9190672040], [171892632.8488696814, 129747589.0754736960], [171892653.7437453866, 129747601.9505184442], [172039928.8316406608, 129835875.2411088347], [172039950.0361926258, 129835887.5994899422], [172071912.7124511003, 129853994.2319388986], [172071955.9993136823, 129854017.3692489862], [172104768.6254730225, 129870533.8572769314], [172104790.6817092299, 129870544.6222688705], [172260008.8953126371, 129943957.3698800802], [172260031.2090920806, 129943967.5903426558], [172293614.7366621494, 129958854.1442833692], [172293660.0829395950, 129958872.9273265004], [172327933.6062606275, 129972093.6841675043], [172327956.6114437878, 129972102.2354338467], [172489623.1145076454, 130029947.4351750016], [172489646.3226206303, 130029955.4192904234], [172524527.2737725079, 130041478.5290703326], [172524574.2427554429, 130041492.7769555300], [172559978.5904714465, 130051290.4794935584], [172560002.3230490088, 130051296.7346809506], [172726560.1787742078, 130093017.3056575507], [172726584.0577139556, 130093022.9765343964], [172762426.5098204613, 130101071.6683072448], [172762474.6491718590, 130101081.2438195944], [172798668.8580611050, 130107361.5348235518], [172798693.0894754231, 130107365.4336911291], [172968538.2546600401, 130132559.5839973986], [172968562.5744592845, 130132562.8870220333], [173005021.3451130986, 130137059.6474861801], [173005070.1912246943, 130137064.4584082663], [173041705.6912699938, 130139766.8552426547], [173041730.1881592572, 130139768.3602421731], [173213226.9610165358, 130148193.4564382732], [173213251.4874623418, 130148194.3598007709], [173249975.4587714672, 130149095.8826947808], [173250024.5412285328, 130149095.8826947808], [173286748.5125376582, 130148194.3598007709], [173286773.0389834642, 130148193.4564382732], [173458269.8118407428, 130139768.3602421731], [173458294.3087300062, 130139766.8552426547], [173494929.8087753057, 130137064.4584082663], [173494978.6548869014, 130137059.6474861801], [173531437.4255407155, 130132562.8870220333], [173531461.7453399599, 130132559.5839973986], [173701306.9105245769, 130107365.4336911291], [173701331.1419388950, 130107361.5348235518], [173737525.3508281410, 130101081.2438195944], [173737573.4901795387, 130101071.6683072448], [173773415.9422860444, 130093022.9765343964], [173773439.8212257922, 130093017.3056575507], [173939997.6769509912, 130051296.7346809506], [173940021.4095285535, 130051290.4794935584], [173975425.7572445571, 130041492.7769555300], [173975472.7262274921, 130041478.5290703326], [174010353.6773793697, 130029955.4192904234], [174010376.8854923546, 130029947.4351750016], [174172043.3885564208, 129972102.2354337722], [174172066.3937395811, 129972093.6841674298], [174206339.9170604050, 129958872.9273265153], [174206385.2633378506, 129958854.1442833841], [174239968.7909073532, 129943967.5903429091], [174239991.1046867967, 129943957.3698803335], [174395209.3182908297, 129870544.6222688407], [174395231.3745270371, 129870533.8572769016], [174428044.0006861687, 129854017.3692490757], [174428087.2875487506, 129853994.2319389880], [174460049.9638076723, 129835887.5994897783], [174460071.1683596373, 129835875.2411086708], [174607346.2562550902, 129747601.9505181462], [174607367.1511307955, 129747589.0754733980], [174638402.8766010404, 129727935.9190673530], [174638443.6871725619, 129727908.6503152549], [174668477.6940754652, 129706756.3161260784], [174668497.5851885378, 129706741.9388444126], [174806411.2077703774, 129604458.2253182083], [174806430.7400564551, 129604443.3642143458], [174835390.6738363206, 129581842.8100694865], [174835428.6150887012, 129581811.6724883765], [174863244.7087301612, 129557817.3451010287], [174863263.0948420465, 129557801.0873798728], [174990487.0685328543, 129442491.9989938438], [174990505.0501227677, 129442475.2949514389], [175017110.2922200263, 129417144.9987577051], [175017144.9987582266, 129417110.2922194898], [175042475.2949506342, 129390505.0501236469], [175042491.9989930391, 129390487.0685337633], [175157801.0873802602, 129263263.0948416293], [175157817.3451014161, 129263244.7087297291], [175181811.6724881828, 129235428.6150889397], [175181842.8100692928, 129235390.6738365740], [175204443.3642146587, 129206430.7400560975], [175204458.2253185213, 129206411.2077700049], [175306741.9388444126, 129068497.5851884931], [175306756.3161260784, 129068477.6940754205], [175327908.6503151953, 129038443.6871726215], [175327935.9190672934, 129038402.8766010851], [175347589.0754733980, 129007367.1511307508], [175347601.9505181611, 129007346.2562550604], [175435875.2411087751, 128860071.1683594286], [175435887.5994898677, 128860049.9638074636], [175453994.2319389284, 128828087.2875487953], [175454017.3692490160, 128828044.0006862283], [175470533.8572773635, 128795231.3745260984], [175470544.6222693026, 128795209.3182898760], [175543957.3698801398, 128639991.1046872139], [175543967.5903427005, 128639968.7909077853], [175558854.1442832351, 128606385.2633381337], [175558872.9273263812, 128606339.9170606583], [175572093.6841673851, 128572066.3937396556], [175572102.2354337275, 128572043.3885565102], [175629947.4351749122, 128410376.8854926229],
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

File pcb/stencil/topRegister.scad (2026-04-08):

// Generated by SolidPython 1.1.3 on 2026-03-23 19:39:00


scale(v = 0.0000010000) {
	translate(v = [-173250000, -65150000, 0]) {
		difference() {
			linear_extrude(convexity = 10, height = 2850000) {
				polygon(points = [[176748911.7473246753, 89882274.4174628854], [176640880.1747894883, 89983888.5447175354], [176538012.4928120077, 90090709.9987348914], [176440551.2296521664, 90202486.0481248945], [176348734.7025354207, 90318943.3724204749], [176262787.4258913398, 90439797.2042649090], [176182919.5623615086, 90564752.0257367939], [176109326.4088972509, 90693502.2909681052], [176042187.9192110598, 90825733.1732783020], [175981668.2637438178, 90961121.3350059092], [175927915.4282270074, 91099335.7181504071], [175881060.8518216610, 91240038.3538883775], [175841219.1057141721, 91382885.1889993101], [175808487.6129639745, 91527526.9271531701], [175782946.4102773666, 91673609.8830349147], [175764657.9522987604, 91820776.8471907824], [175753666.9588936567, 91968667.9594922662], [175750000.0000000000, 92116933.9533492625], [175750000.0000000000, 127614031.9769262373], [175749999.6963495016, 127614056.6185331643], [175748179.5610017180, 127687898.5018143207], [175748178.6502346396, 127687923.1284563839], [175739772.0340961814, 127858345.4017978758], [175739770.5278793275, 127858369.8483167142], [175737068.1429093778, 127894930.1312516332], [175737063.3369316161, 127894978.8769856691], [175732573.9323061407, 127931362.9726718068], [175732570.6354283094, 127931387.2426443994], [175707365.4336911142, 128101306.9105247408], [175707361.5348235369, 128101331.1419390440], [175701081.2438195646, 128137525.3508284241], [175701071.6683072150, 128137573.4901798218], [175693022.9765343368, 128173415.9422863722], [175693017.3056574762, 128173439.8212261200], [175651296.7346811295, 128339997.6769503355], [175651290.4794937372, 128340021.4095278978], [175641492.7769555449, 128375425.7572444677], [175641478.5290703475, 128375472.7262274027], [175629955.4192903638, 128410353.6773795038], [175629947.4351749420, 128410376.8854924887], [175572102.2354337275, 128572043.3885565102], [175572093.6841673851, 128572066.3937396556], [175558872.9273263812, 128606339.9170606583], [175558854.1442832351, 128606385.2633381337], [175543967.5903427005, 128639968.7909077853], [175543957.3698801398, 128639991.1046872139], [175470544.6222693026, 128795209.3182898760], [175470533.8572773635, 128795231.3745260984], [175454017.3692490160, 128828044.0006862283], [175453994.2319389284, 128828087.2875487953], [175435887.5994898677, 128860049.9638074636], [175435875.2411087751, 128860071.1683594286], [175347601.9505181611, 129007346.2562550604], [175347589.0754733980, 129007367.1511307508], [175327935.9190672934, 129038402.8766010851], [175327908.6503151953, 129038443.6871726215], [175306756.3161260784, 129068477.6940754205], [175306741.9388444126, 129068497.5851884931], [175204458.2253185213, 129206411.2077700049], [175204443.3642146587, 129206430.7400560975], [175181842.8100695014, 129235390.6738362759], [175181811.6724883914, 129235428.6150886416], [175157817.3451009393, 129263244.7087302655], [175157801.0873797834, 129263263.0948421657], [175042491.9989930391, 129390487.0685337633], [175042475.2949506342, 129390505.0501236469], [175017144.9987582266, 129417110.2922194898], [175017110.2922200263, 129417144.9987577051], [174990505.0501227677, 129442475.2949514389], [174990487.0685328543, 129442491.9989938438], [174863263.0948420465, 129557801.0873798728], [174863244.7087301612, 129557817.3451010287], [174835428.6150887012, 129581811.6724883765], [174835390.6738363206, 129581842.8100694865], [174806430.7400564551, 129604443.3642143458], [174806411.2077703774, 129604458.2253182083], [174668497.5851882696, 129706741.9388445914], [174668477.6940751970, 129706756.3161262572], [174638443.6871728003, 129727908.6503151059], [174638402.8766012788, 129727935.9190672040], [174607367.1511303186, 129747589.0754736960], [174607346.2562546134, 129747601.9505184442], [174460071.1683593392, 129835875.2411088347], [174460049.9638073742, 129835887.5994899422], [174428087.2875488997, 129853994.2319388986], [174428044.0006863177, 129854017.3692489862], [174395231.3745269775, 129870533.8572769314], [174395209.3182907701, 129870544.6222688705], [174239991.1046873629, 129943957.3698800802], [174239968.7909079194, 129943967.5903426558], [174206385.2633378506, 129958854.1442833692], [174206339.9170604050, 129958872.9273265004], [174172066.3937393725, 129972093.6841675043], [174172043.3885562122, 129972102.2354338467], [174010376.8854923546, 130029947.4351750016], [174010353.6773793697, 130029955.4192904234], [173975472.7262274921, 130041478.5290703326], [173975425.7572445571, 130041492.7769555300], [173940021.4095285535, 130051290.4794935584], [173939997.6769509912, 130051296.7346809506], [173773439.8212257922, 130093017.3056575507], [173773415.9422860444, 130093022.9765343964], [173737573.4901795387, 130101071.6683072448], [173737525.3508281410, 130101081.2438195944], [173701331.1419388950, 130107361.5348235518], [173701306.9105245769, 130107365.4336911291], [173531461.7453399599, 130132559.5839973986], [173531437.4255407155, 130132562.8870220333], [173494978.6548869014, 130137059.6474861801], [173494929.8087753057, 130137064.4584082663], [173458294.3087300062, 130139766.8552426547], [173458269.8118407428, 130139768.3602421731], [173286773.0389834642, 130148193.4564382732], [173286748.5125376582, 130148194.3598007709], [173250024.5412285328, 130149095.8826947808], [173249975.4587714672, 130149095.8826947808], [173213251.4874623418, 130148194.3598007709], [173213226.9610165358, 130148193.4564382732], [173041730.1881592572, 130139768.3602421731], [173041705.6912699938, 130139766.8552426547], [173005070.1912246943, 130137064.4584082663], [173005021.3451130986, 130137059.6474861801], [172968562.5744592845, 130132562.8870220333], [172968538.2546600401, 130132559.5839973986], [172798693.0894754231, 130107365.4336911291], [172798668.8580611050, 130107361.5348235518], [172762474.6491718590, 130101081.2438195944], [172762426.5098204613, 130101071.6683072448], [172726584.0577139556, 130093022.9765343964], [172726560.1787742078, 130093017.3056575507], [172560002.3230490088, 130051296.7346809506], [172559978.5904714465, 130051290.4794935584], [172524574.2427554429, 130041492.7769555300], [172524527.2737725079, 130041478.5290703326], [172489646.3226206303, 130029955.4192904234], [172489623.1145076454, 130029947.4351750016], [172327956.6114435792, 129972102.2354337722], [172327933.6062604189, 129972093.6841674298], [172293660.0829395950, 129958872.9273265153], [172293614.7366621494, 129958854.1442833841], [172260031.2090926468, 129943967.5903429091], [172260008.8953132033, 129943957.3698803335], [172104790.6817091703, 129870544.6222688407], [172104768.6254729629, 129870533.8572769016], [172071955.9993138313, 129854017.3692490757], [172071912.7124512494, 129853994.2319389880], [172039950.0361923277, 129835887.5994897783], [172039928.8316403627, 129835875.2411086708], [171892653.7437449098, 129747601.9505181462], [171892632.8488692045, 129747589.0754733980], [171861597.1233989596, 129727935.9190673530], [171861556.3128274381, 129727908.6503152549], [171831522.3059245348, 129706756.3161260784], [171831502.4148114622, 129706741.9388444126], [171693588.7922296226, 129604458.2253182083], [171693569.2599435449, 129604443.3642143458], [171664609.3261636794, 129581842.8100694865], [171664571.3849112988, 129581811.6724883765], [171636755.2912698388, 129557817.3451010287], [171636736.9051579535, 129557801.0873798728], [171509512.9314671457, 129442491.9989938438], [171509494.9498772323, 129442475.2949514389], [171482889.7077799737, 129417144.9987577051], [171482855.0012417734, 129417110.2922194898], [171457524.7050493658, 129390505.0501236469], [171457508.0010069609, 129390487.0685337633], [171342198.9126197398, 129263263.0948416293], [171342182.6548985839, 129263244.7087297291], [171318188.3275118172, 129235428.6150889397], [171318157.1899307072, 129235390.6738365740], [171295556.6357853413, 129206430.7400560975], [171295541.7746814787, 129206411.2077700049], [171193258.0611555874, 129068497.5851884931], [171193243.6838739216, 129068477.6940754205], [171172091.3496848047, 129038443.6871726215], [171172064.0809327066, 129038402.8766010851], [171152410.9245266020, 129007367.1511307508], [171152398.0494818389, 129007346.2562550604], [171064124.7588912249, 128860071.1683594286], [171064112.4005101323, 128860049.9638074636], [171046005.7680610716, 128828087.2875487953], [171045982.6307509840, 128828044.0006862283], [171029466.1427226365, 128795231.3745260984], [171029455.3777306974, 128795209.3182898760], [170956042.6301198602, 128639991.1046872139], [170956032.4096572995, 128639968.7909077853], [170941145.8557167649, 128606385.2633381337], [170941127.0726736188, 128606339.9170606583], [170927906.3158326149, 128572066.3937396556], [170927897.7645662725, 128572043.3885565102], [170870052.5648250878, 128410376.8854926229],
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

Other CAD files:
pcb/stencil/bottomRegister.stl

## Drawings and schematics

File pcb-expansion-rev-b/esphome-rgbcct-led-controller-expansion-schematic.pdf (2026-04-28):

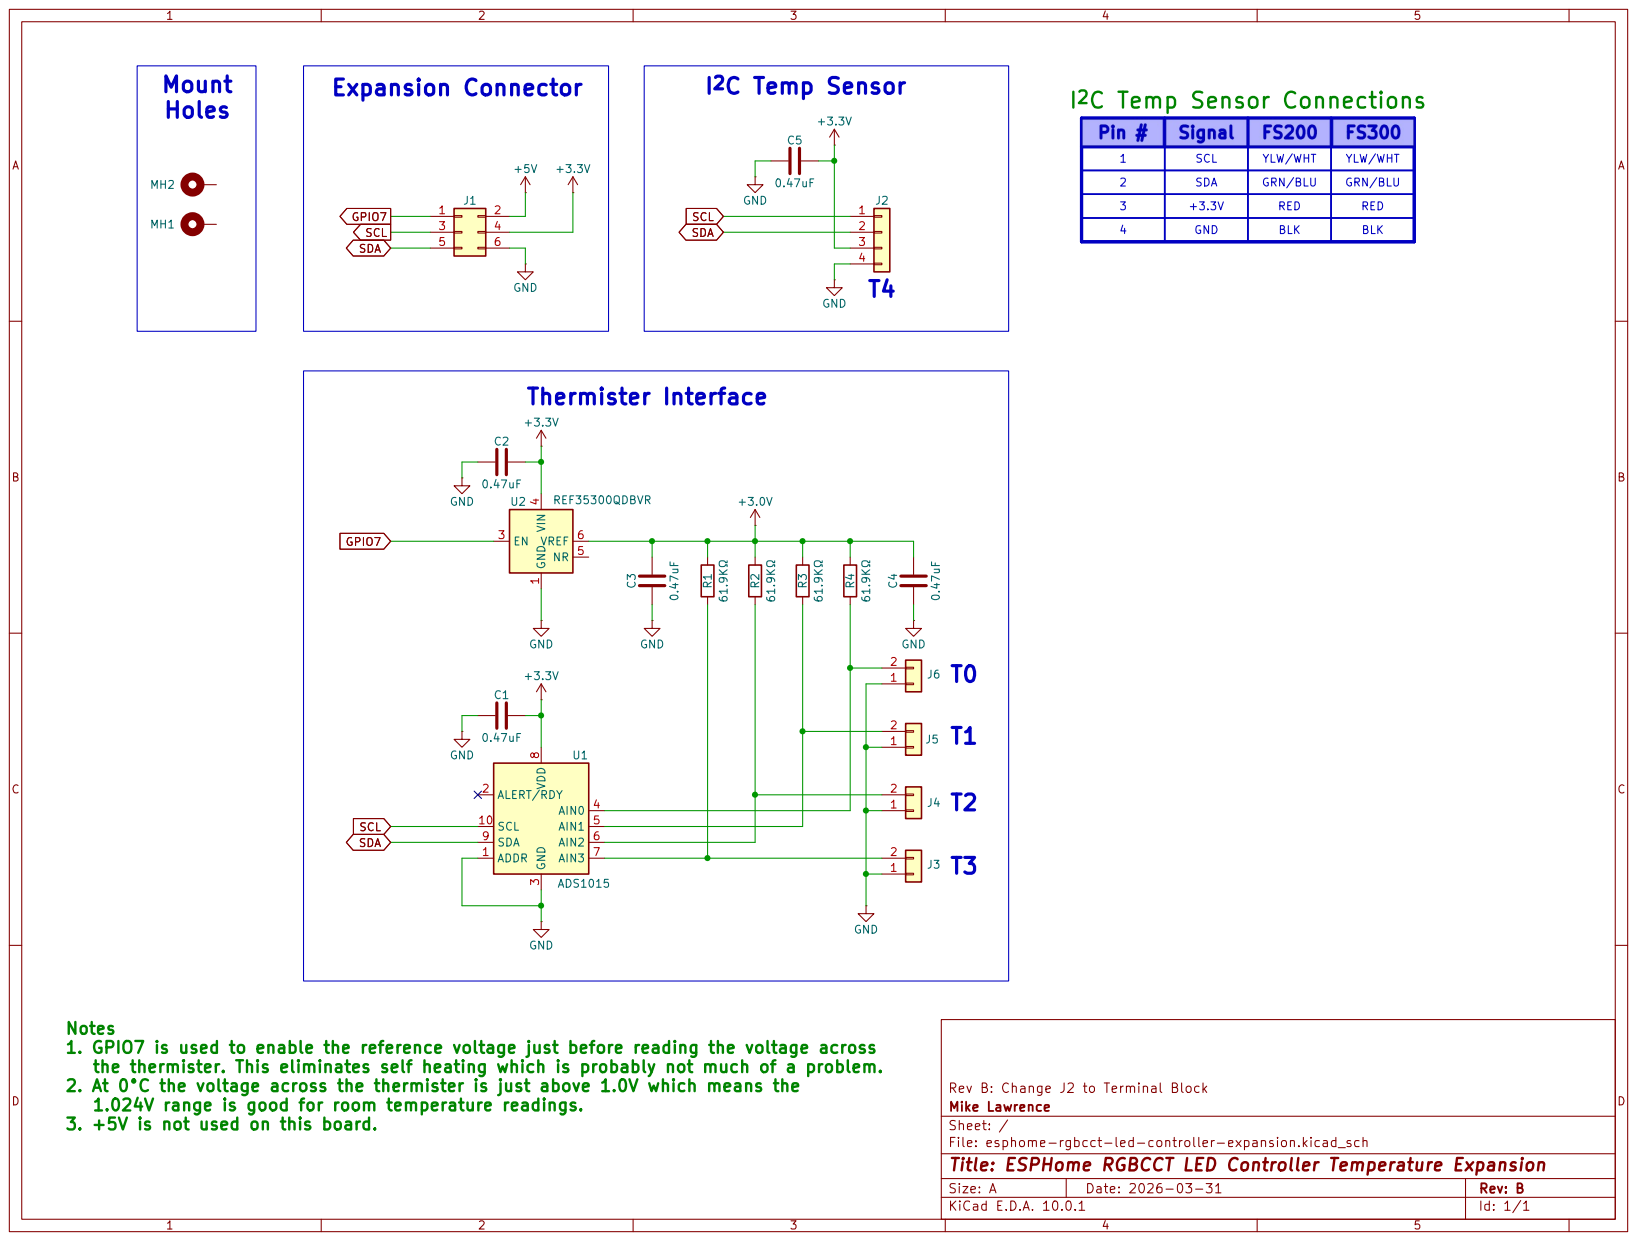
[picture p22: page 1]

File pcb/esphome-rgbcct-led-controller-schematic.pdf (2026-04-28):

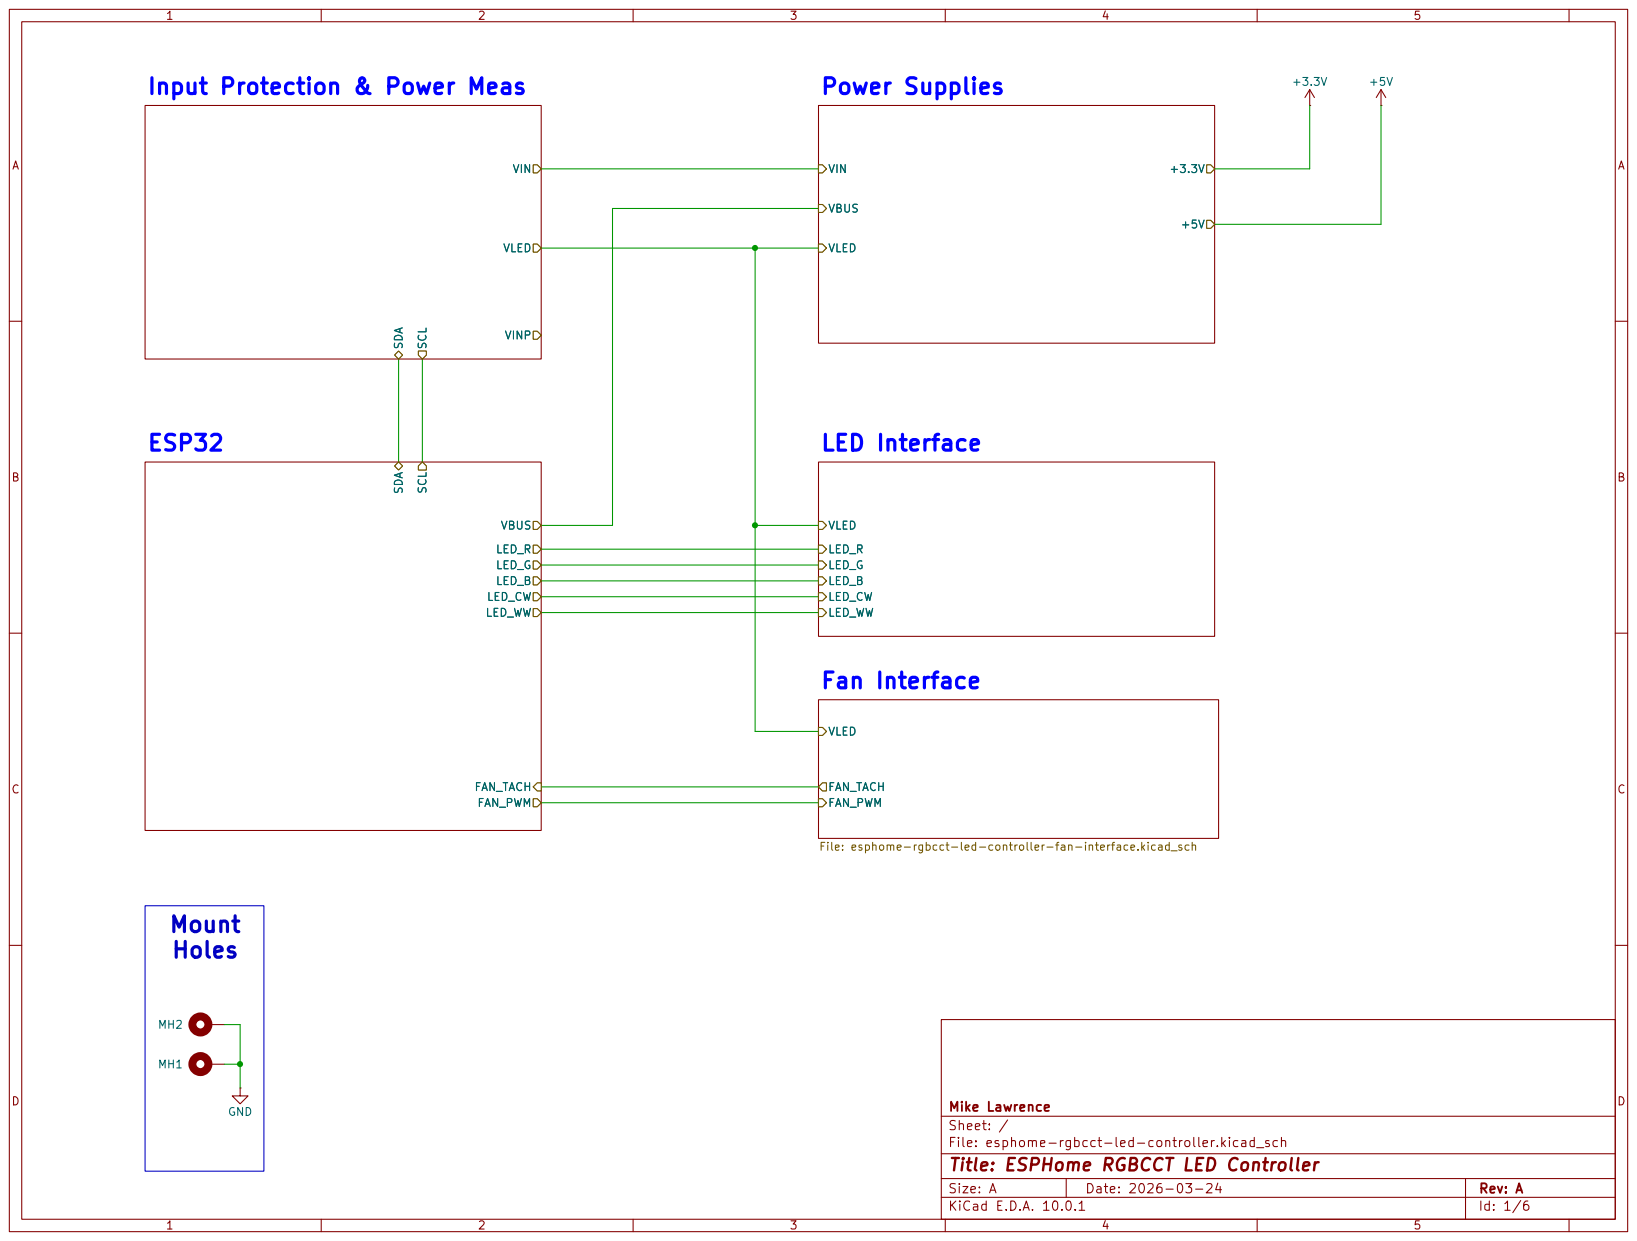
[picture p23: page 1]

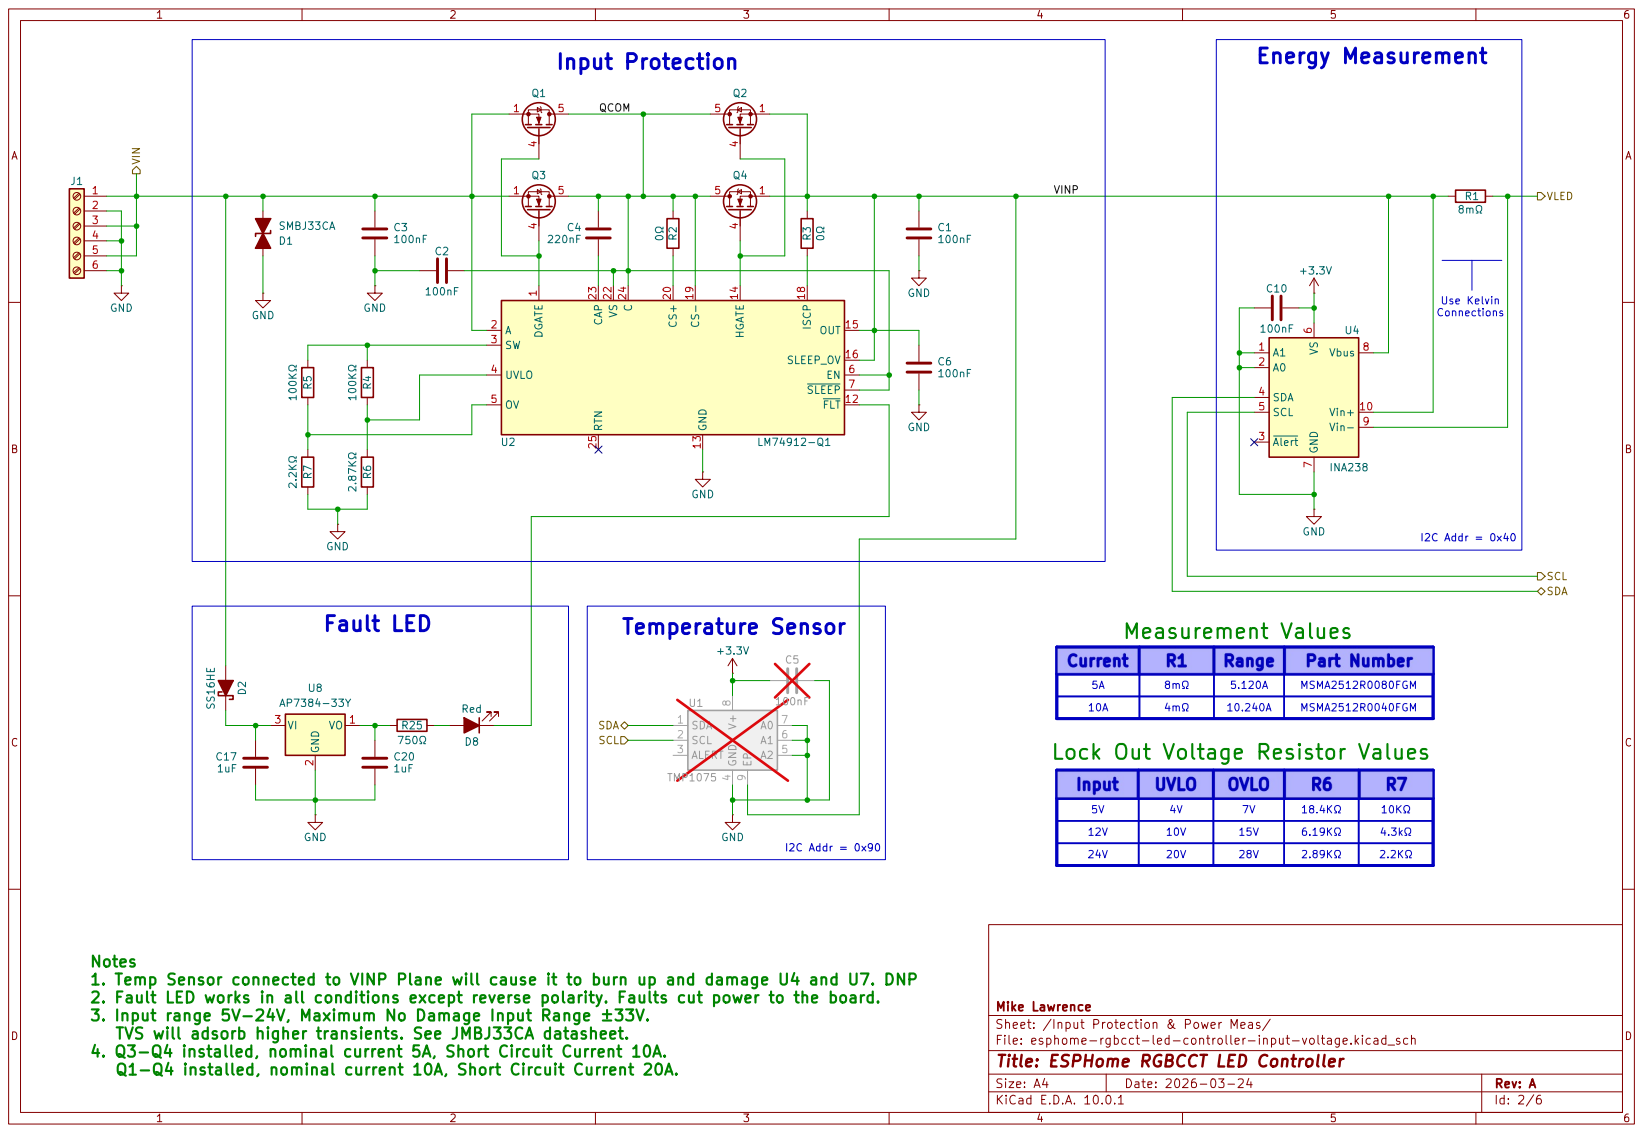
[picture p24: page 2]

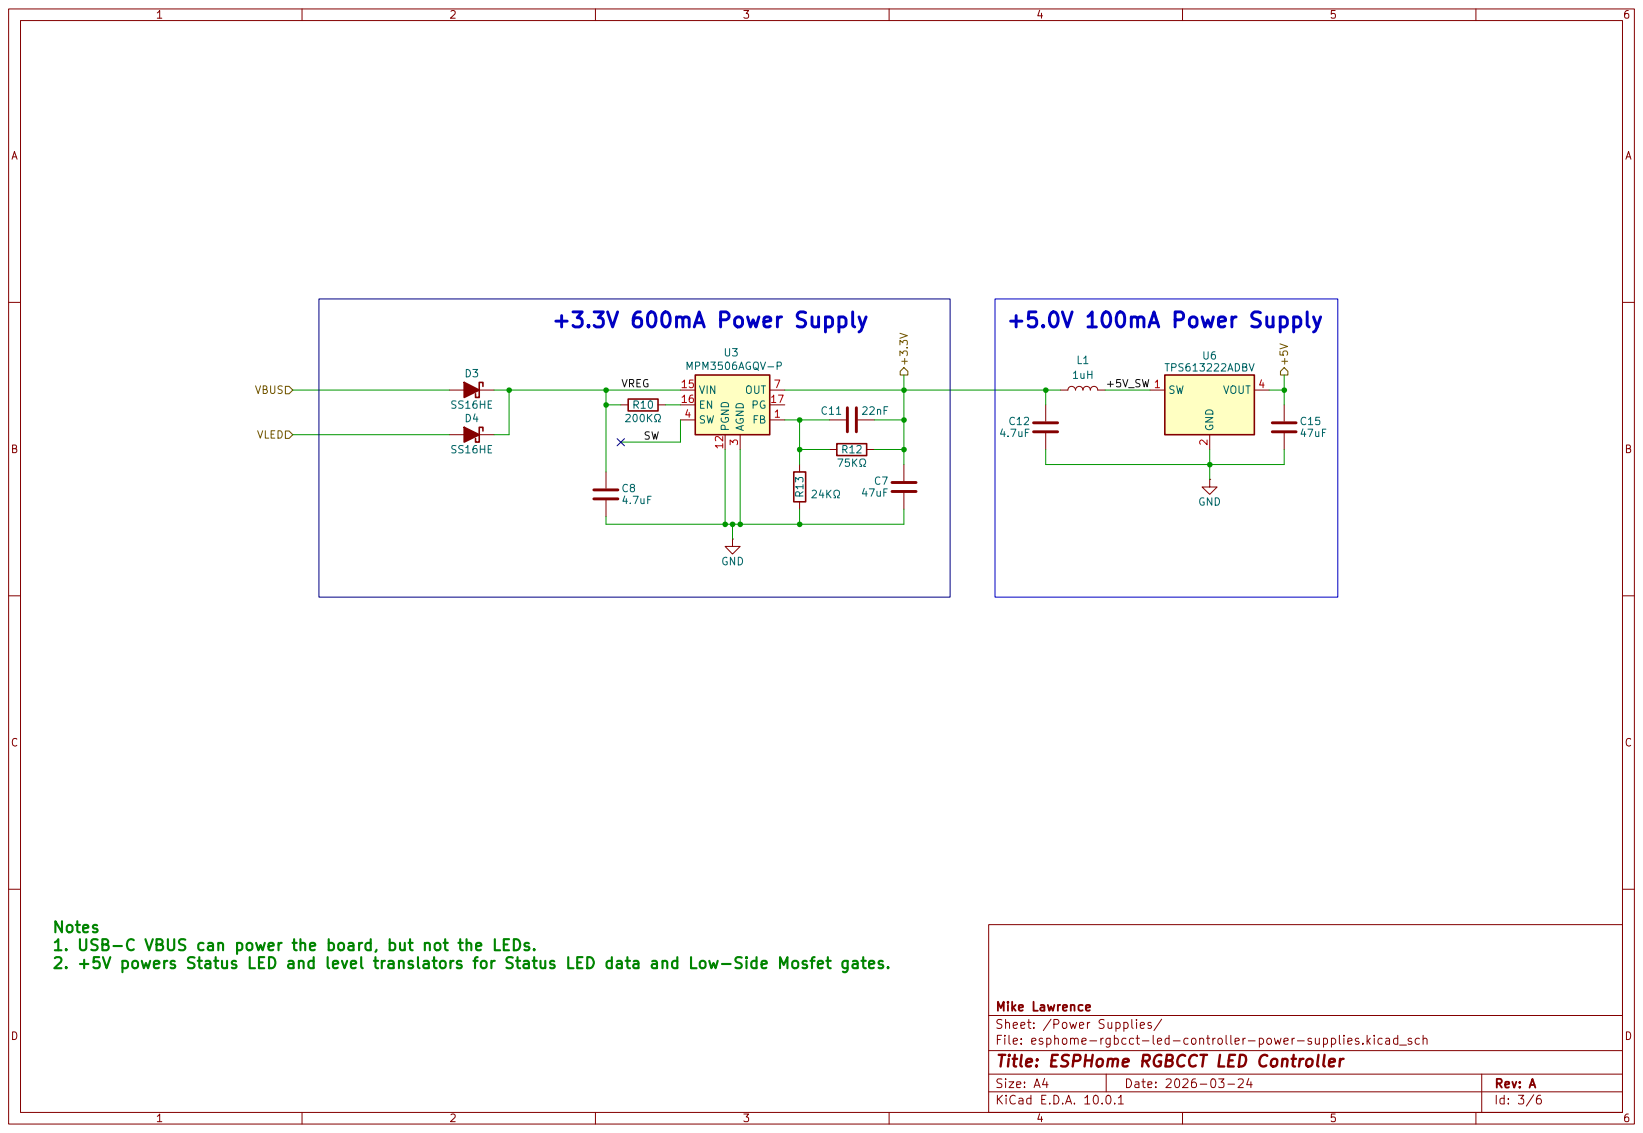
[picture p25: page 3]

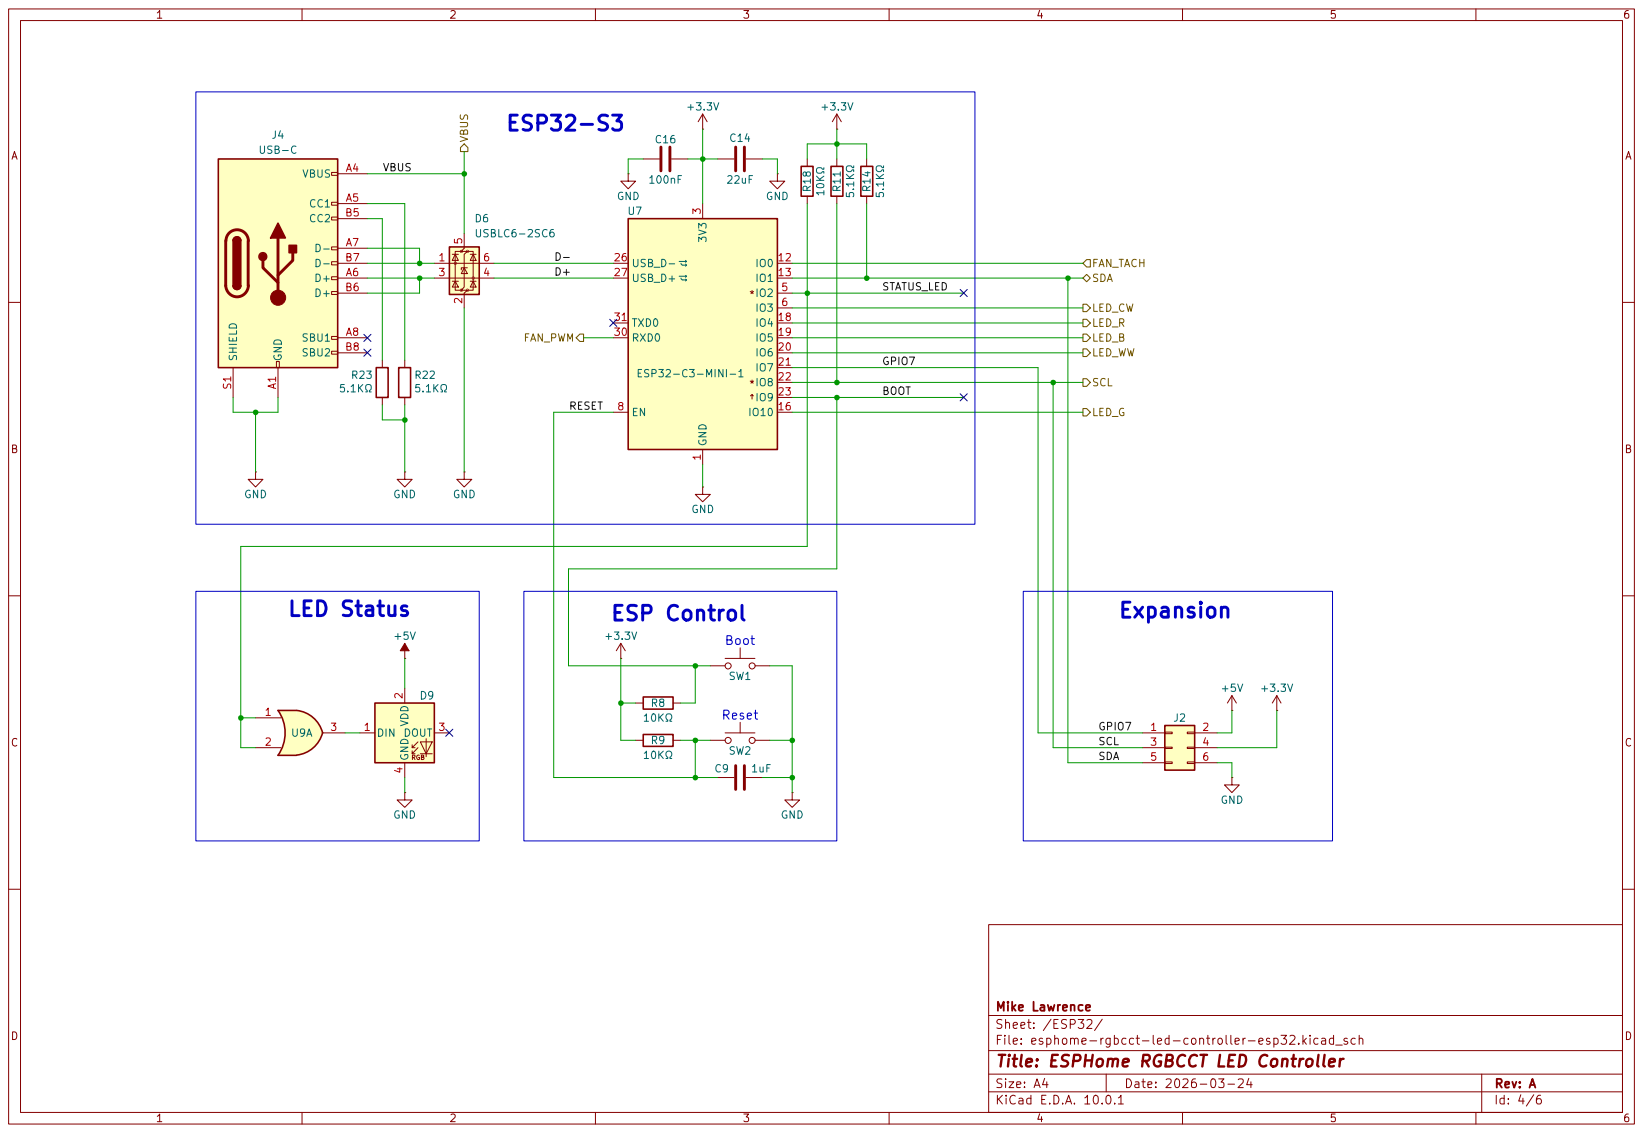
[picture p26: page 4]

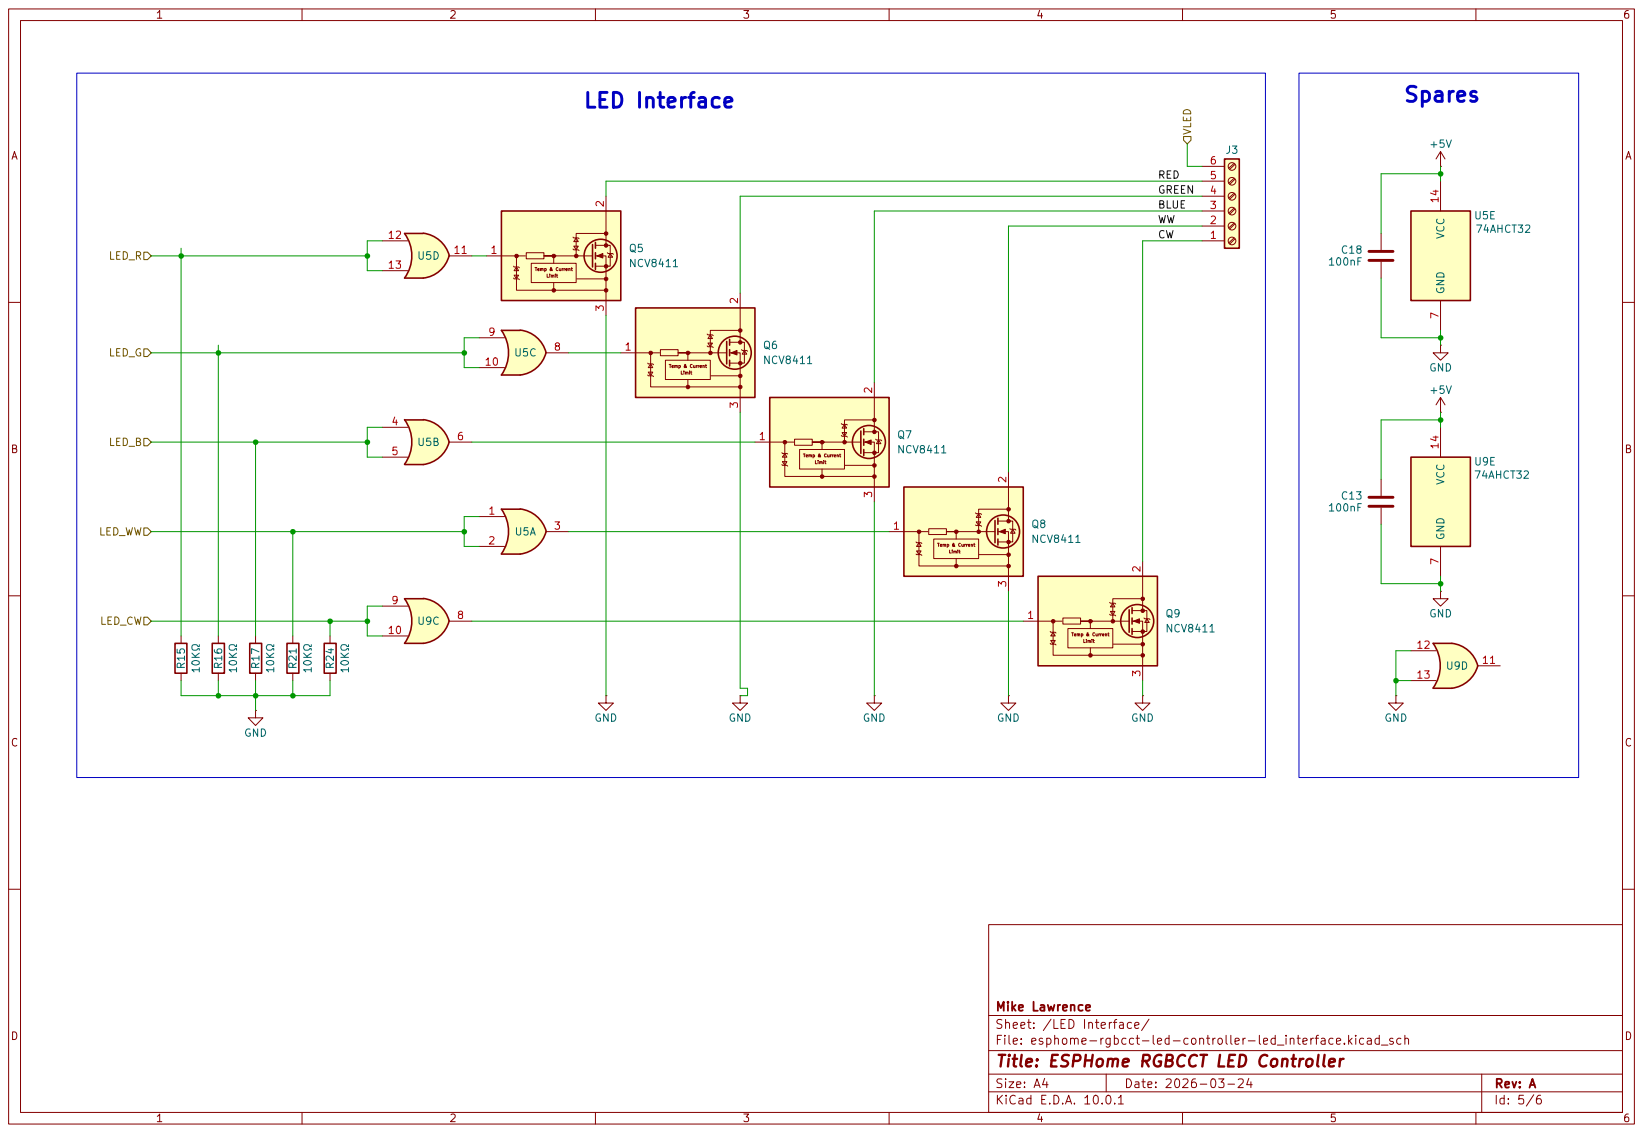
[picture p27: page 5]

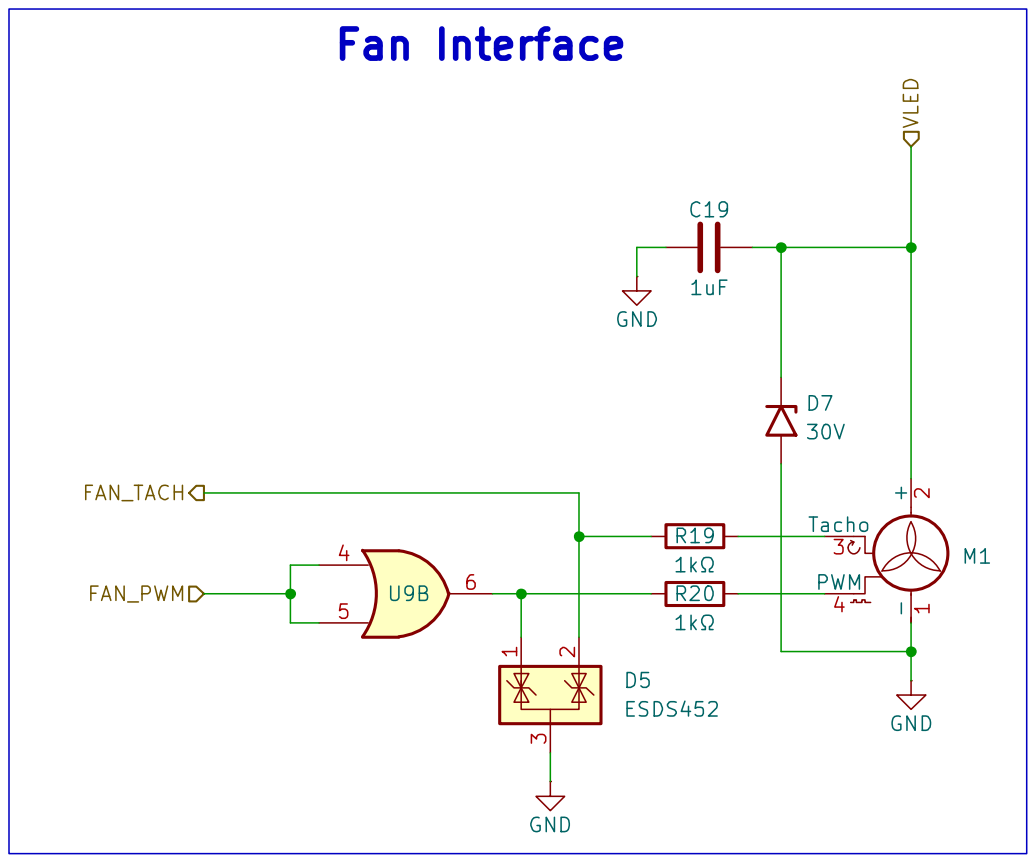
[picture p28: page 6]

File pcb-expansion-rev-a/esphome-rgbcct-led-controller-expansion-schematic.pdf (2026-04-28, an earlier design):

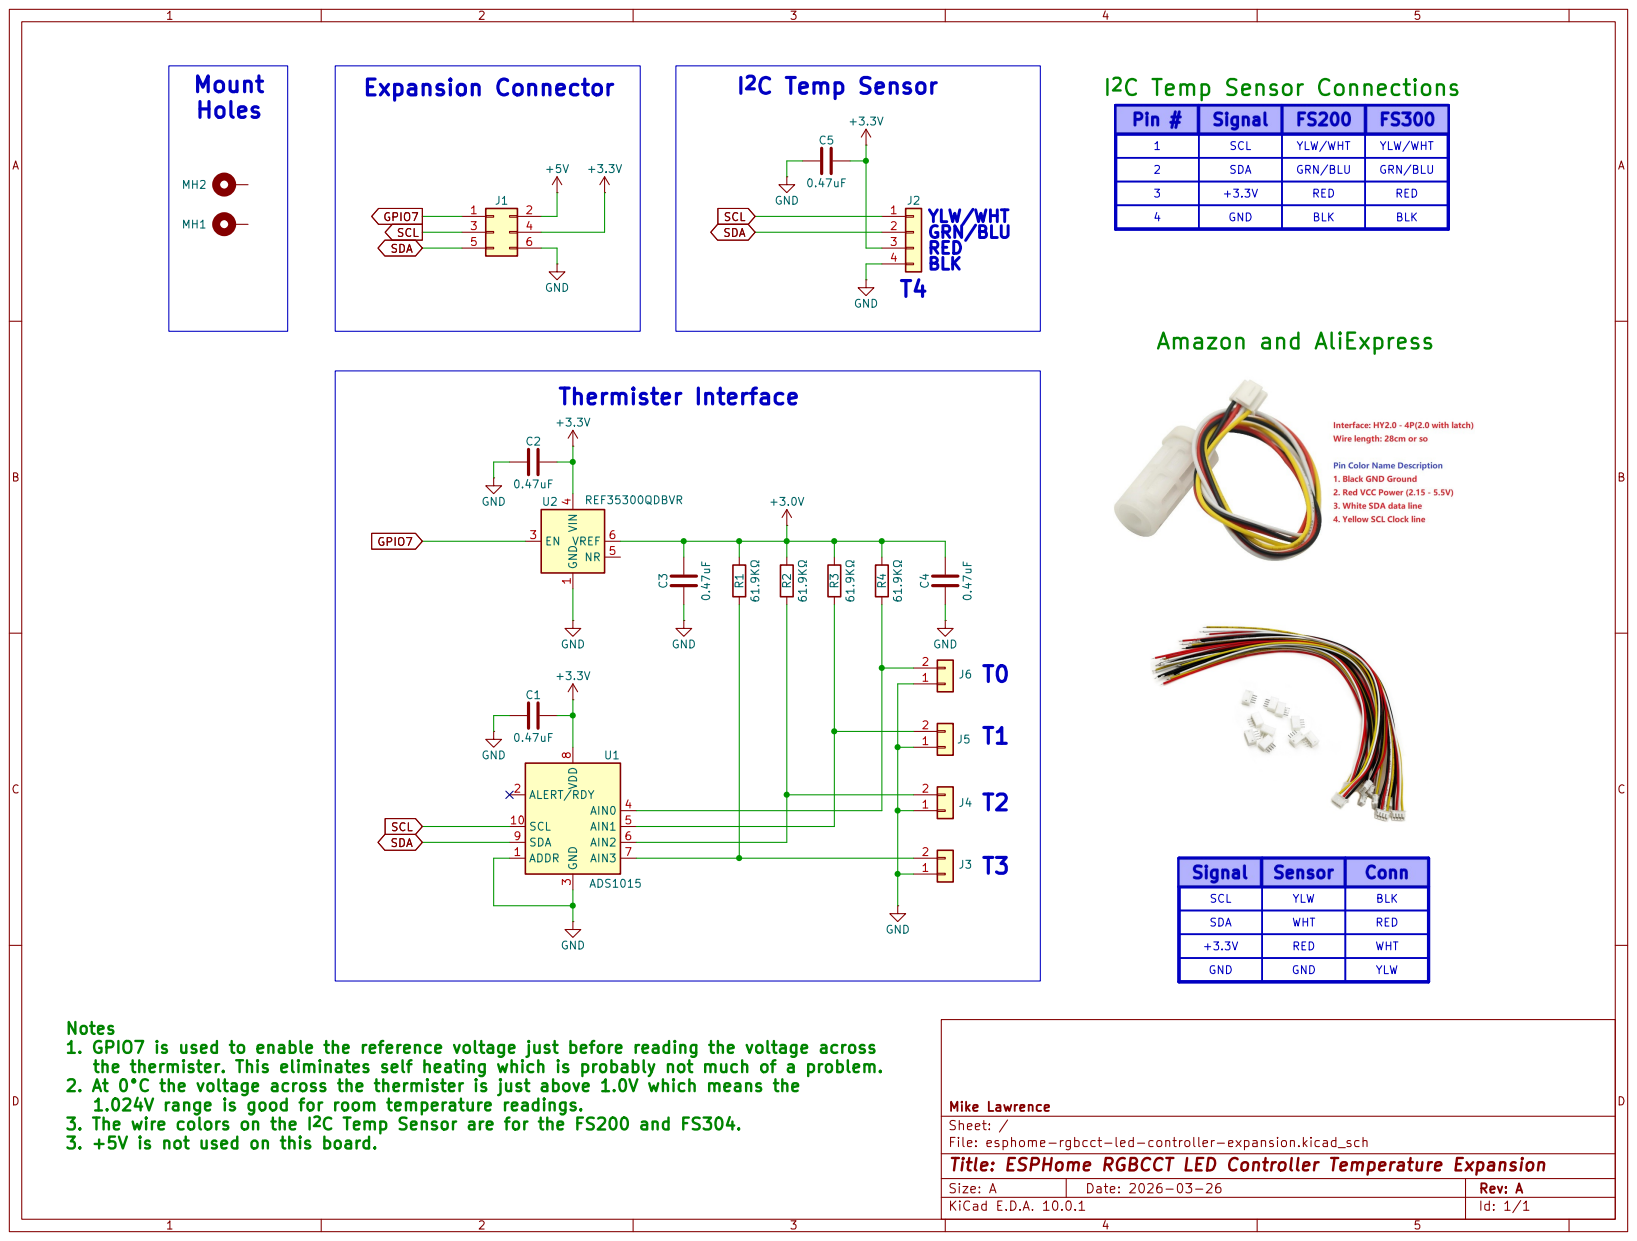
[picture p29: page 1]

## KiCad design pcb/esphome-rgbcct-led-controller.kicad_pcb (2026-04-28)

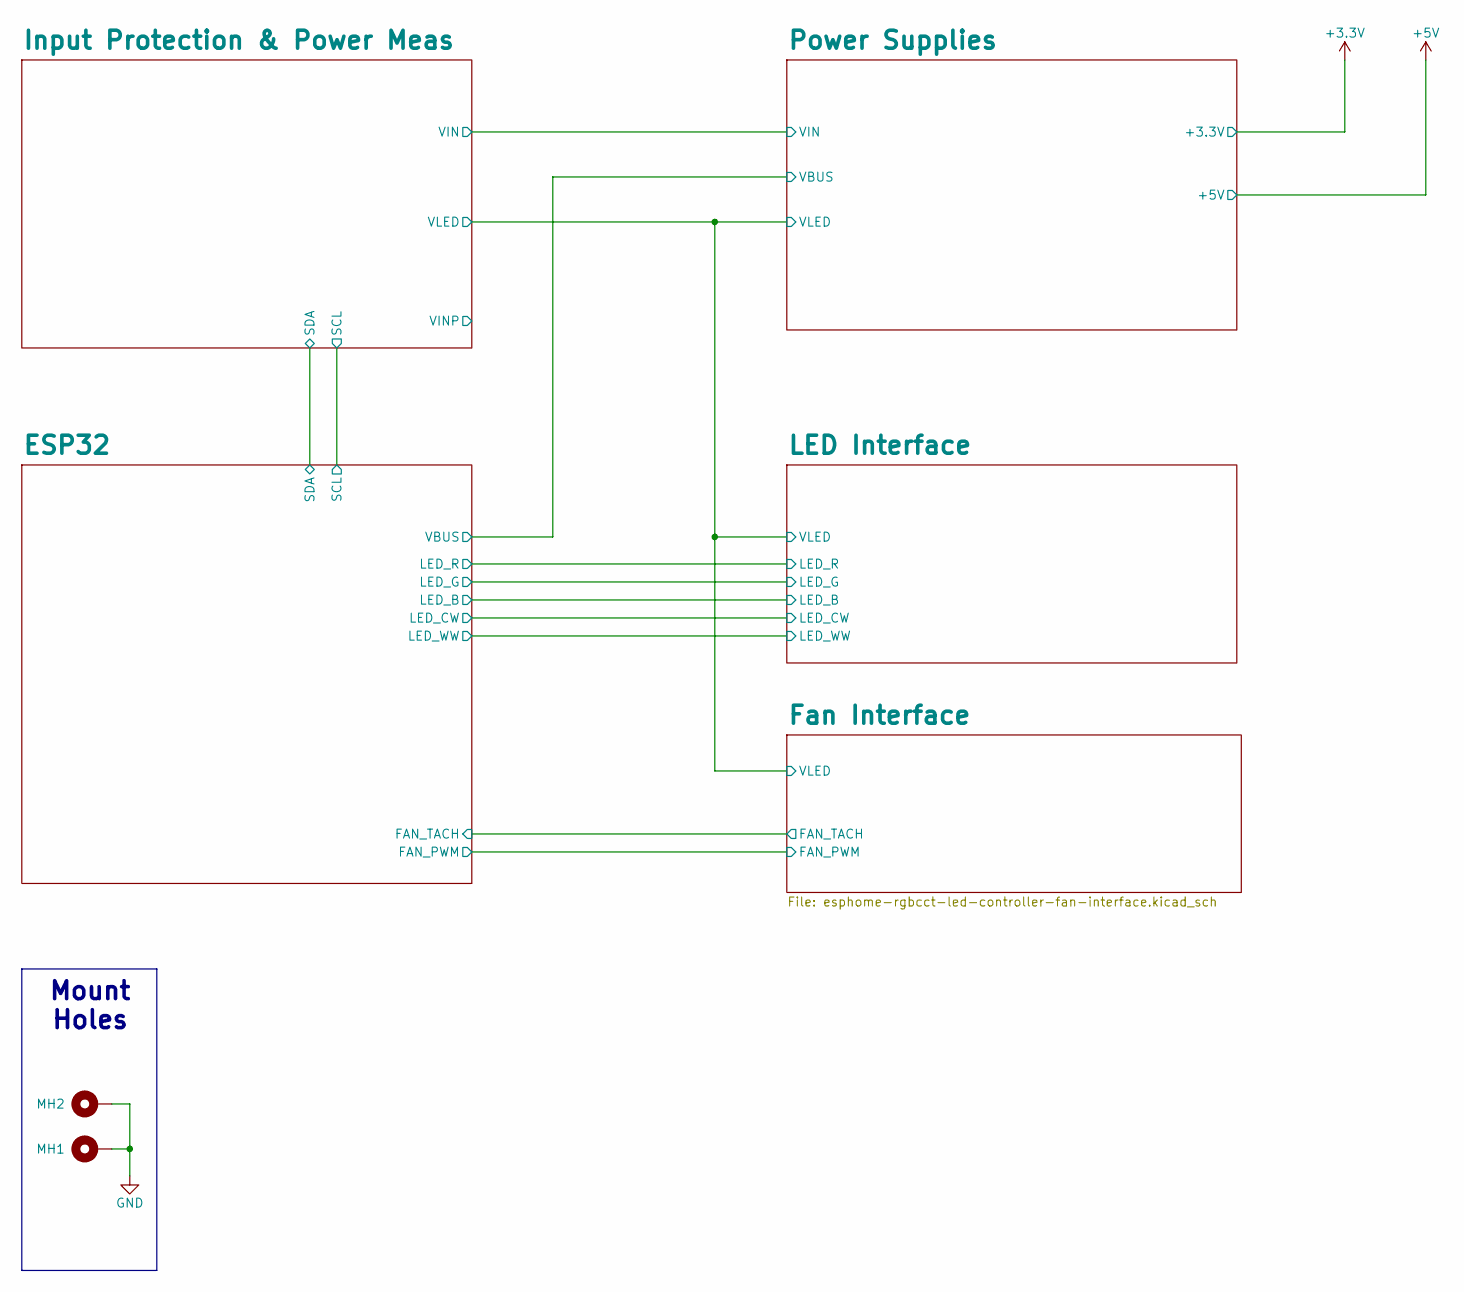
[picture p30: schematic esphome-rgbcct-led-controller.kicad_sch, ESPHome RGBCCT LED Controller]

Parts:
MH1, MH2: 97730606332R; Part Number 97730606332R

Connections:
GND: MH1.1 (1_1), MH2.1 (1_1); also elsewhere on the board

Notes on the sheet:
Mount Holes

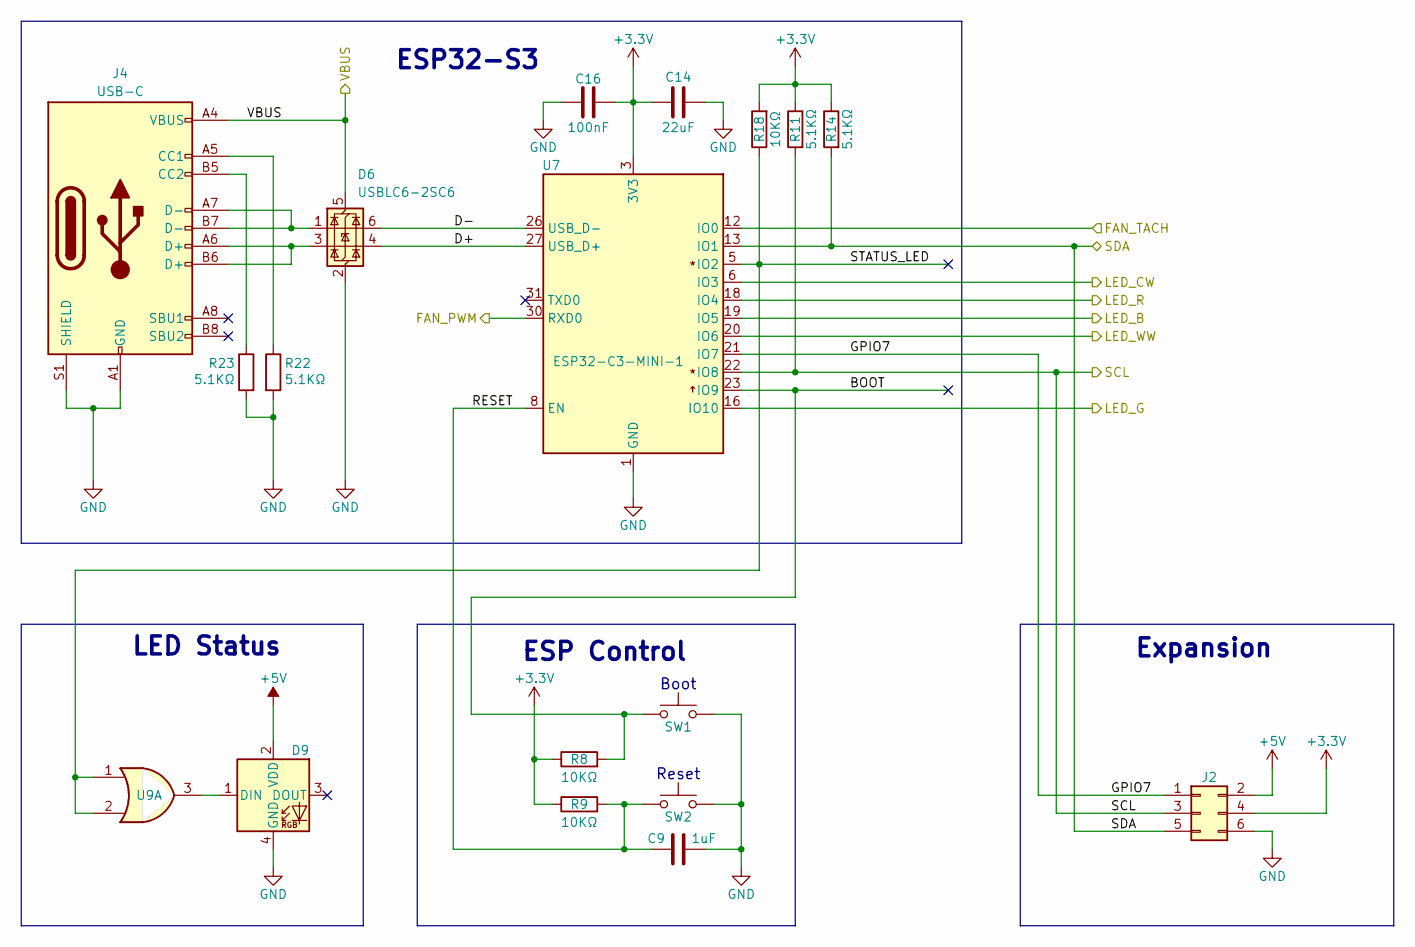
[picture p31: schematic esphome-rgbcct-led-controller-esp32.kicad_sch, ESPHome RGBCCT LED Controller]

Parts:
C9: 1uF; C_0402_1005Metric; Part Number GRM155R61H105KE05D
C14: 22uF; C_0603_1608Metric; Part Number GRM188R60J226MEA0D
C16: 100nF; C_0402_1005Metric; Part Number CL05B104KB54PNC
D6: USBLC6-2SC6; SOT-23-6; Part Number USBLC6-2SC6
D9: SK6812-4020; Part Number 4691
J2: SAMTEC_SFMC-103-01-L-D; Part Number SFMC-103-01-L-D
J4: USB-C; HRO_TYPE-C-31-M-12; Part Number 1332645
R8, R9, R18: 10KΩ; R_0402_1005Metric; Part Number CRCW040210K0FKED
R11, R14, R22, R23: 5.1KΩ; R_0402_1005Metric; Part Number CRCW04025K10FKED
SW1, SW2: SW_SPST_B3U-1000P-B; Part Number B3U-1000P
U7: ESP32-C3-MINI-1; ESP32-C3-MINI-1-N4X; Part Number ESP32-C3-MINI-1-N4X
U9: 74AHCT32; DHWQFN-14-1EP_2.5x3mm_P0.5mm_EP1x1.5mm; Part Number SN74AHCT32BQAR

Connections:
+3.3V: C14.1, C16.2, J2.4, R8.1, R9.1, R11.1, R14.1, R18.2, U7.3 (3V3); also elsewhere on the board
+5V: D9.2 (VDD), J2.2; also elsewhere on the board
/ESP32/BOOT: R8.2, SW1.2, U7.23 (IO9)
/ESP32/D+: D6.4 (I/O2), U7.27 (USB_D+)
/ESP32/D-: D6.6 (I/O1), U7.26 (USB_D-)
/ESP32/FAN_PWM: U7.30 (RXD0); also elsewhere on the board
/ESP32/FAN_TACH: U7.12 (IO0); also elsewhere on the board
/ESP32/GPIO7: J2.1, U7.21 (IO7)
/ESP32/LED_B: U7.19 (IO5); also elsewhere on the board
/ESP32/LED_CW: U7.6 (IO3); also elsewhere on the board
/ESP32/LED_G: U7.16 (IO10); also elsewhere on the board
/ESP32/LED_R: U7.18 (IO4); also elsewhere on the board
/ESP32/LED_WW: U7.20 (IO6); also elsewhere on the board
/ESP32/RESET: C9.1, R9.2, SW2.2, U7.8 (EN)
/ESP32/SCL: J2.3, R11.2, U7.22 (IO8); also elsewhere on the board
/ESP32/SDA: J2.5, R14.2, U7.13 (IO1); also elsewhere on the board
/ESP32/STATUS_LED: R18.1, U7.5 (IO2), U9.1, U9.2
/ESP32/VBUS: D6.5 (VBUS), J4.A4 (VBUS), J4.B4 (VBUS); also elsewhere on the board
GND: C9.2, C14.2, C16.1, D6.2 (GND), D9.4 (GND), J2.6, J4.A1 (GND), J4.B1 (GND), J4.S1 (SHIELD), R22.2, R23.2, SW1.1, SW2.1, U7.1 (GND), U7.2 (GND), U7.11 (GND), U7.14 (GND), U7.36 (GND), U7.37 (GND), U7.38 (GND), U7.39 (GND), U7.40 (GND), U7.41 (GND), U7.42 (GND), U7.43 (GND), U7.44 (GND), U7.45 (GND), U7.46 (GND), U7.47 (GND), U7.48 (GND), U7.49 (GND), U7.50 (GND), U7.51 (GND), U7.52 (GND), U7.53 (GND); also elsewhere on the board
unnamed: D6.1 (I/O1), J4.A7 (D-), J4.B7 (D-)
unnamed: D6.3 (I/O2), J4.A6 (D+), J4.B6 (D+)
unnamed: D9.1 (DIN), U9.3
unnamed: J4.A5 (CC1), R22.1
unnamed: J4.B5 (CC2), R23.1

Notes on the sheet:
ESP32-S3
Expansion
Reset
ESP Control
Boot
LED Status

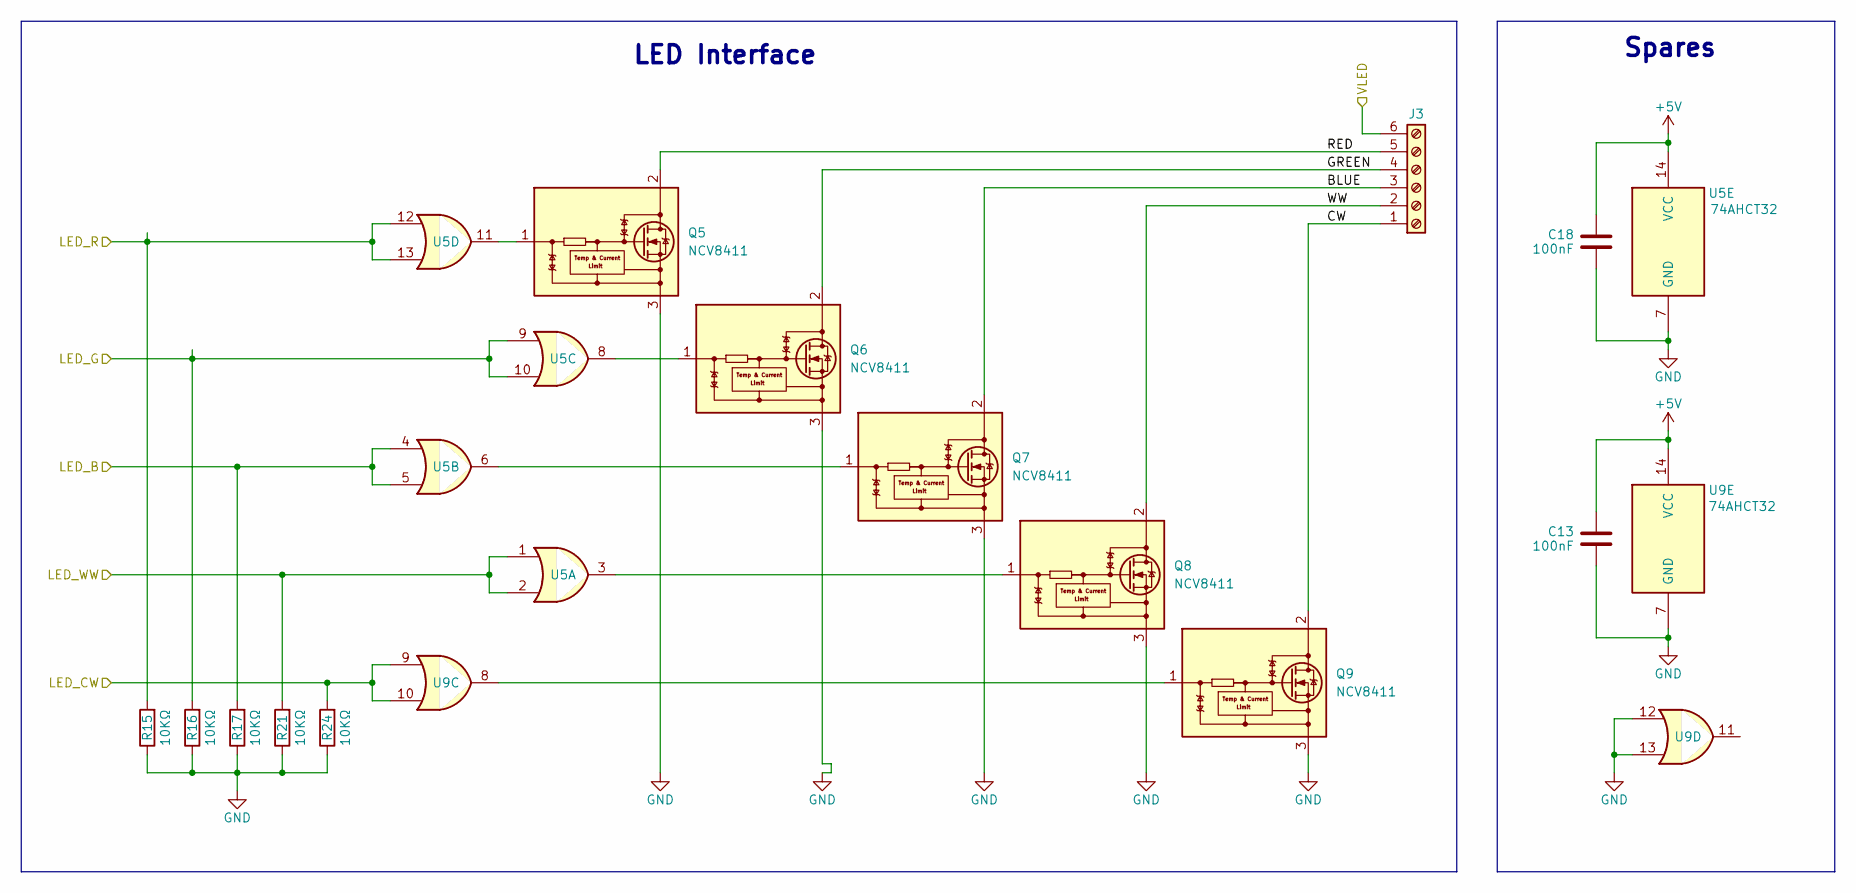
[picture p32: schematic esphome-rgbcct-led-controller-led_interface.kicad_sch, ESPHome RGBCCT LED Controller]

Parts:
C13, C18: 100nF; C_0402_1005Metric; Part Number CL05B104KB54PNC
J3: 1017507; Part Number 1017507
Q5, Q6, Q7, Q8, Q9: NCV8411; TO-252-2; Part Number NCV8411DTRKG
R15, R16, R17, R21, R24: 10KΩ; R_0402_1005Metric; Part Number CRCW040210K0FKED
U5, U9: 74AHCT32; DHWQFN-14-1EP_2.5x3mm_P0.5mm_EP1x1.5mm; Part Number SN74AHCT32BQAR

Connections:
+5V: C13.1, C18.1, U5.14 (VCC), U9.14 (VCC); also elsewhere on the board
/ESP32/LED_B: R17.2, U5.4, U5.5; also elsewhere on the board
/ESP32/LED_CW: R24.2, U9.9, U9.10; also elsewhere on the board
/ESP32/LED_G: R16.2, U5.9, U5.10; also elsewhere on the board
/ESP32/LED_R: R15.2, U5.12, U5.13; also elsewhere on the board
/ESP32/LED_WW: R21.2, U5.1, U5.2; also elsewhere on the board
/Fan Interface/VLED: J3.6; also elsewhere on the board
/LED Interface/BLUE: J3.3, Q7.2 (D)
/LED Interface/CW: J3.1, Q9.2 (D)
/LED Interface/GREEN: J3.4, Q6.2 (D)
/LED Interface/RED: J3.5, Q5.2 (D)
/LED Interface/WW: J3.2, Q8.2 (D)
GND: C13.2, C18.2, Q5.3 (S), Q6.3 (S), Q7.3 (S), Q8.3 (S), Q9.3 (S), R15.1, R16.1, R17.1, R21.1, R24.1, U5.7 (GND), U9.7 (GND), U9.12, U9.13; also elsewhere on the board
unnamed: Q5.1 (G), U5.11
unnamed: Q6.1 (G), U5.8
unnamed: Q7.1 (G), U5.6
unnamed: Q8.1 (G), U5.3
unnamed: Q9.1 (G), U9.8

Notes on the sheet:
Spares
LED Interface

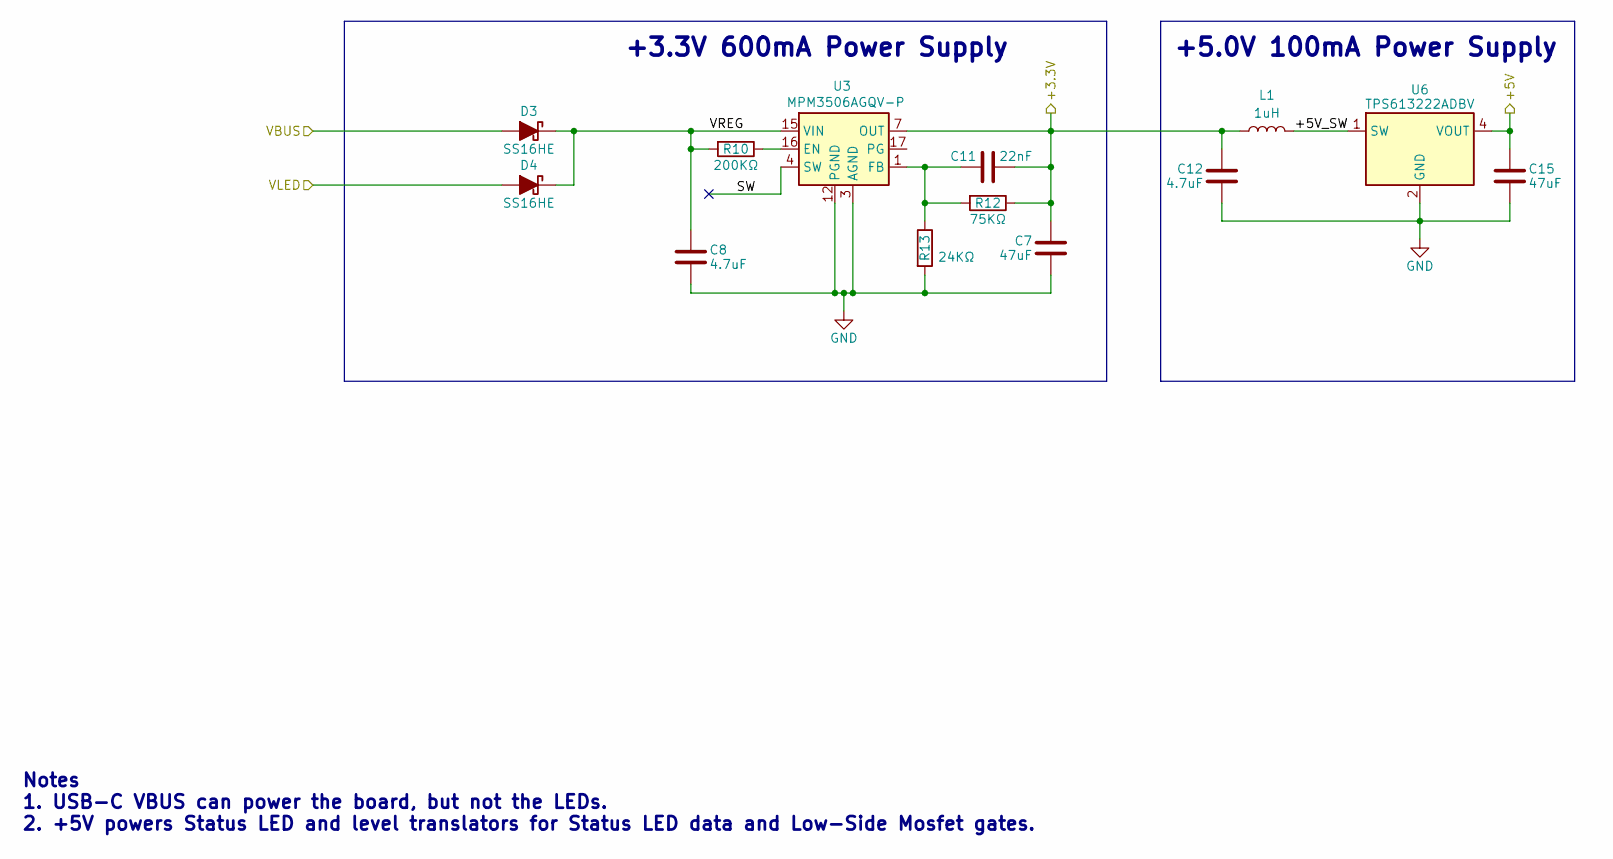
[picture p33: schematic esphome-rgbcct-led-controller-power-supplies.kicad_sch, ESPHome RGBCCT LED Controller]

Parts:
C7, C15: 47uF; C_0805_2012Metric; Part Number MSASL21GBB5476MTNA01
C8, C12: 4.7uF; C_0805_2012Metric; Part Number MSASU21GBB5475KTNA01
C11: 22nF; C_0402_1005Metric; Part Number GRM155R71H223KA12J
D3, D4: SS16HE; Part Number SS16HE
L1: 1uH; L_0805_2012Metric; Part Number MLP2012S1R0MT0S1
R10: 200KΩ; R_0402_1005Metric; Part Number CRCW0402200KFKED
R12: 75KΩ; R_0402_1005Metric; Part Number RT0402BRD0775KL
R13: 24KΩ; R_0402_1005Metric; Part Number RT0402BRD0724KL
U3: MPM3506AGQV-P; QFN-19; Part Number MPM3506AGQV-P; Mouser Part Number 946-MPM3506AGQV-P
U6: TPS613222ADBV; SOT-23-5; Part Number TPS613222ADBVR

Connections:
+3.3V: C7.1, C11.2, C12.1, L1.1, R12.1, U3.7 (OUT), U3.8 (OUT_2), U3.9 (OUT_3), U3.19 (OUT_4); also elsewhere on the board
+5V: C15.1, U6.4 (VOUT); also elsewhere on the board
/ESP32/VBUS: D3.2 (A); also elsewhere on the board
/Fan Interface/VLED: D4.2 (A); also elsewhere on the board
/Power Supplies/+5V_SW: L1.2, U6.1 (SW)
/Power Supplies/SW: U3.4 (SW), U3.5 (SW_2), U3.6 (SW_3), U3.18 (SW_4)
/Power Supplies/VREG: C8.1, D3.1 (K), D4.1 (K), R10.2, U3.15 (VIN)
GND: C7.2, C8.2, C12.2, C15.2, R13.2, U3.3 (AGND), U3.12 (PGND), U3.13 (PGND_2), U6.2 (GND); also elsewhere on the board
unnamed: R10.1, U3.16 (EN)
unnamed: C11.1, R12.2, R13.1, U3.1 (FB)

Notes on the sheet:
+5.0V 100mA Power Supply
+3.3V 600mA Power Supply
Notes 1. USB-C VBUS can power the board, but not the LEDs. 2. +5V powers Status LED and level translators for Status LED data and Low-Side Mosfet gates.

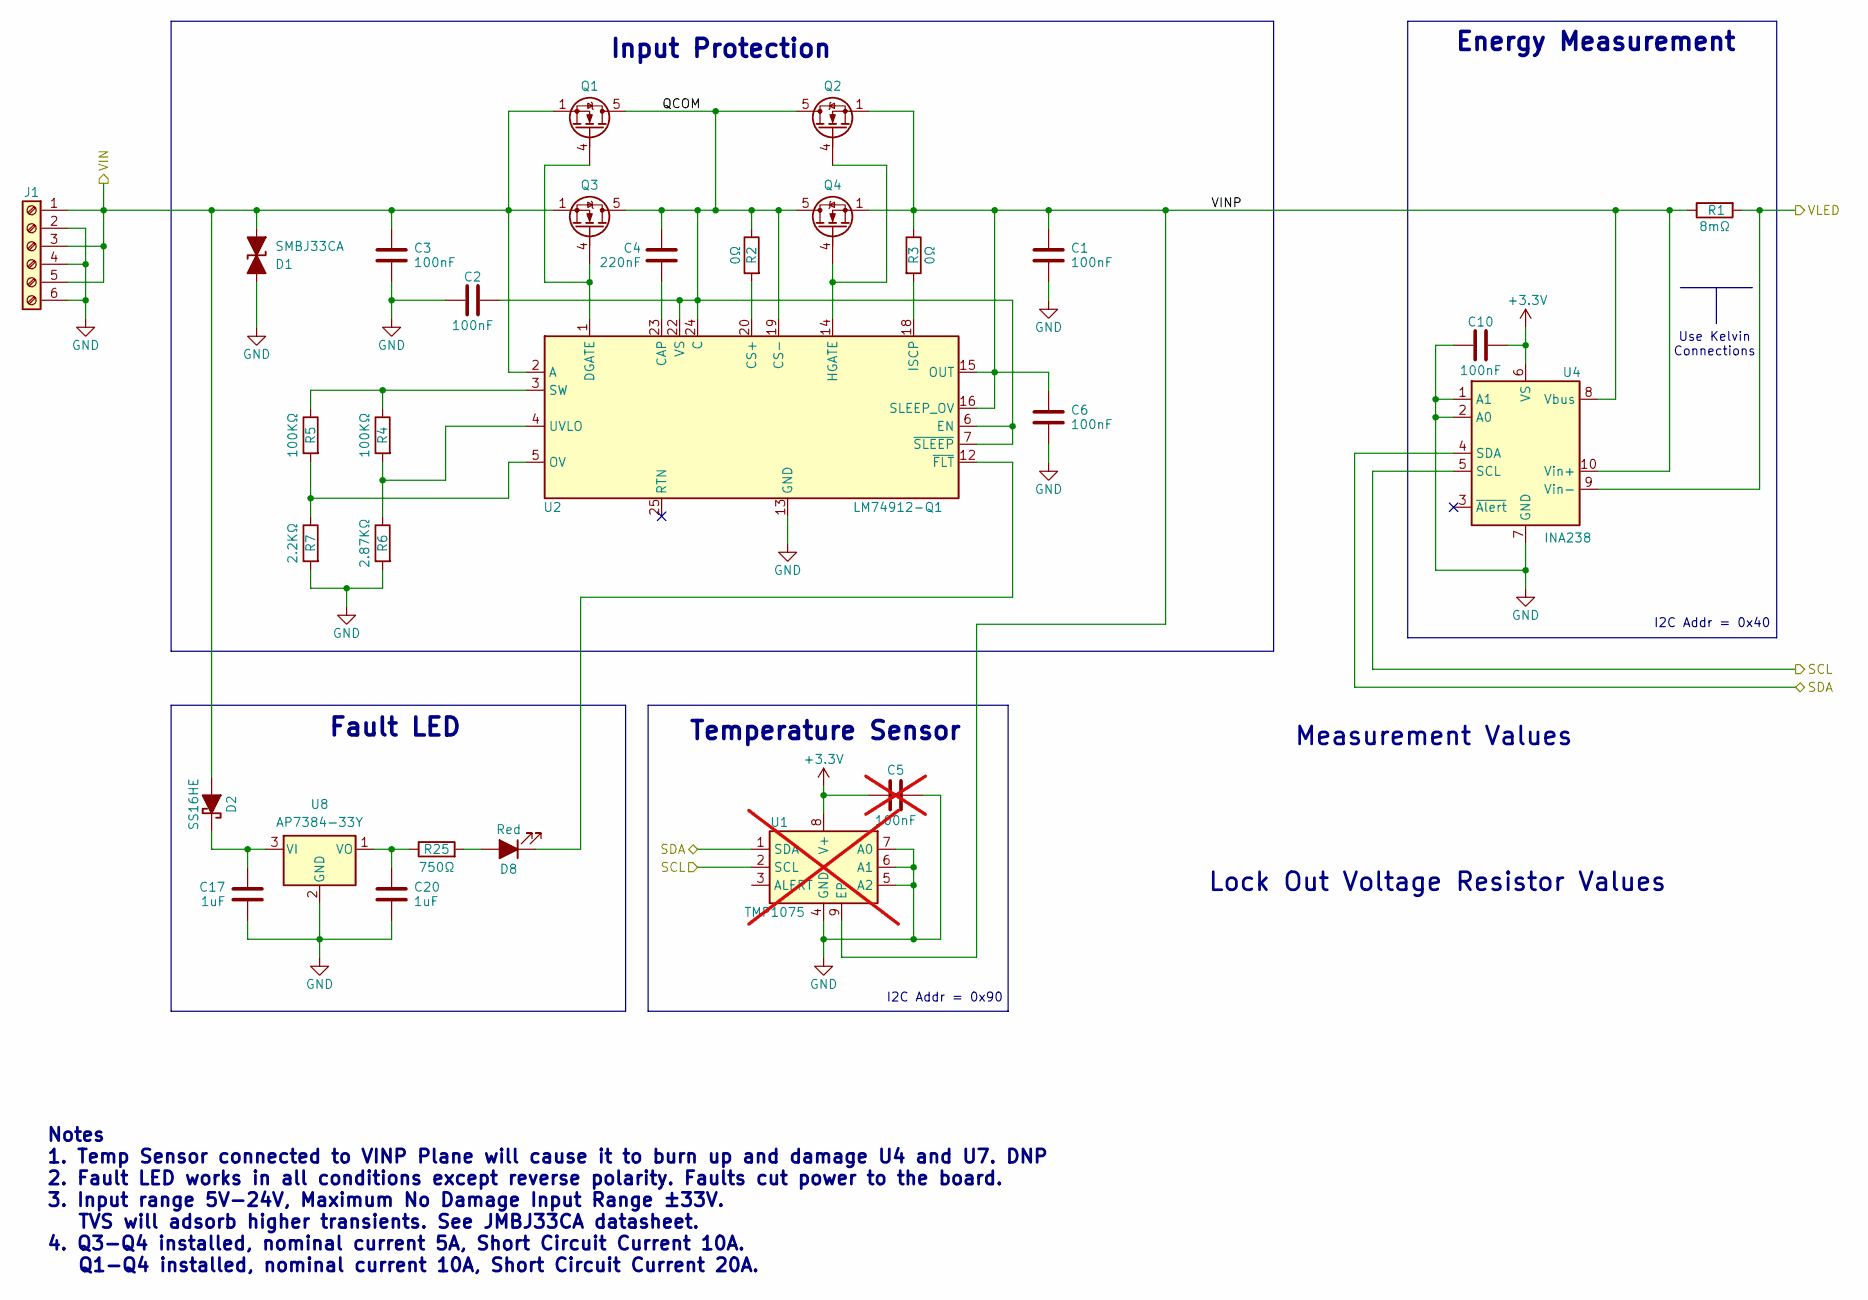
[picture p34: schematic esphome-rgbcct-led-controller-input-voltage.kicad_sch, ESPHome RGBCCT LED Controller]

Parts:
C1, C2, C3, C6, C10: 100nF; C_0402_1005Metric; Part Number CL05B104KB54PNC
C4: 220nF; C_0402_1005Metric; Part Number GRM155R61H224ME01W
C5: 100nF; C_0402_1005Metric; Part Number CL05B104KB54PNC; not fitted
C17, C20: 1uF; C_0402_1005Metric; Part Number GRM155R61H105KE05D
D1: SMBJ33CA; D_SMB; Part Number SMBJ33CA
D2: SS16HE; Part Number SS16HE
D8: Red; APDA3020LSECKJ3PF; Part Number APDA3020LSECK/J3-PF
J1: 1017505; 1017507; Part Number 1017505
Q1, Q2, Q3, Q4: TQM050NB06CR; TRANS_TQM050NB06CR_RLG; Part Number TQM050NB06CR RLG
R1: 8mΩ; R_2512_6332Metric; Part Number MSMA2512R0080FGM
R2, R3: 0Ω; R_0402_1005Metric; Part Number RC0402FR-070RL
R4, R5: 100KΩ; R_0402_1005Metric; Part Number RT0402BRD07100KL
R6: 2.87KΩ; R_0402_1005Metric; Part Number RT0402BRD072K87L
R7: 2.2KΩ; R_0402_1005Metric; Part Number RT0402BRD072K2L
R25: 750Ω; R_0402_1005Metric; Part Number CRCW0402750RFKED
U1: TMP1075; WSON-8-1EP_2x2mm_P0.5mm_EP0.9x1.6mm_ThermalVias; Part Number TMP1075DSGR; not fitted
U2: LM74912-Q1; Texas_RGE0024C_VQFN-24-1EP_4x4mm_P0.5mm_EP2.1x2.1mm; Part Number LM74912QRGERQ1
U4: INA238; VSSOP-10_3x3mm_P0.5mm; Part Number INA238AIDGSR
U8: AP7384-33Y; SOT-89-3; Part Number AP7384-33Y-13

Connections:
+3.3V: C5.2, C10.2, U1.8 (V+), U4.6 (VS); also elsewhere on the board
/ESP32/SCL: U1.2 (SCL), U4.5 (SCL); also elsewhere on the board
/ESP32/SDA: U1.1 (SDA), U4.4 (SDA); also elsewhere on the board
/Fan Interface/VLED: R1.2, U4.9 (Vin-); also elsewhere on the board
/Input Protection & Power Meas/QCOM: C2.2, C4.2, Q1.5 (D), Q2.5 (D), Q3.5 (D), Q4.5 (D), R2.1, U2.6 (EN), U2.7 (~SLEEP), U2.19 (CS-), U2.22 (VS), U2.24 (C)
/Input Protection & Power Meas/VIN: C3.1, D1.1 (A1), D2.2 (A), J1.1, J1.3, J1.5, Q1.1 (S), Q1.2 (S), Q1.3 (S), Q3.1 (S), Q3.2 (S), Q3.3 (S), U2.2 (A)
/Input Protection & Power Meas/VINP: C1.1, C6.1, Q2.1 (S), Q2.2 (S), Q2.3 (S), Q4.1 (S), Q4.2 (S), Q4.3 (S), R1.1, R3.1, U1.9 (EP), U2.15 (OUT), U2.16 (SLEEP_OV), U4.8 (Vbus), U4.10 (Vin+)
GND: C1.2, C2.1, C3.2, C5.1, C6.2, C10.1, C17.2, C20.2, D1.2 (A2), J1.2, J1.4, J1.6, R6.2, R7.2, U1.4 (GND), U1.5 (A2), U1.6 (A1), U1.7 (A0), U2.13 (GND), U4.1 (A1), U4.2 (A0), U4.7 (GND), U8.2 (GND); also elsewhere on the board
unnamed: C17.1, D2.1 (K), U8.3 (VI)
unnamed: D8.2 (A), R25.2
unnamed: D8.1 (K), U2.12 (~FLT)
unnamed: Q1.4 (G), Q3.4 (G), U2.1 (DGATE)
unnamed: Q2.4 (G), Q4.4 (G), U2.14 (HGATE)
unnamed: C4.1, U2.23 (CAP)
unnamed: R2.2, U2.20 (CS+)
unnamed: R3.2, U2.18 (ISCP)
unnamed: R5.2, R7.1, U2.5 (OV)
unnamed: R4.1, R5.1, U2.3 (SW)
unnamed: R4.2, R6.1, U2.4 (UVLO)
unnamed: C20.1, R25.1, U8.1 (VO)

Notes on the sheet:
I2C Addr = 0x40
Energy Measurement
Notes 1. Temp Sensor connected to VINP Plane will cause it to burn up and damage U4 and U7. DNP 2. Fault LED works in all conditions except reverse polarity. Faults cut power to the board. 3. Input range 5V-24V, Maximum No Damage Input Range ±33V. TVS will adsorb higher transients. See JMBJ33CA dat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
I2C Addr = 0x90
Fault LED
Temperature Sensor
Input Protection
Measurement Values
Use Kelvin Connections
Lock Out Voltage Resistor Values

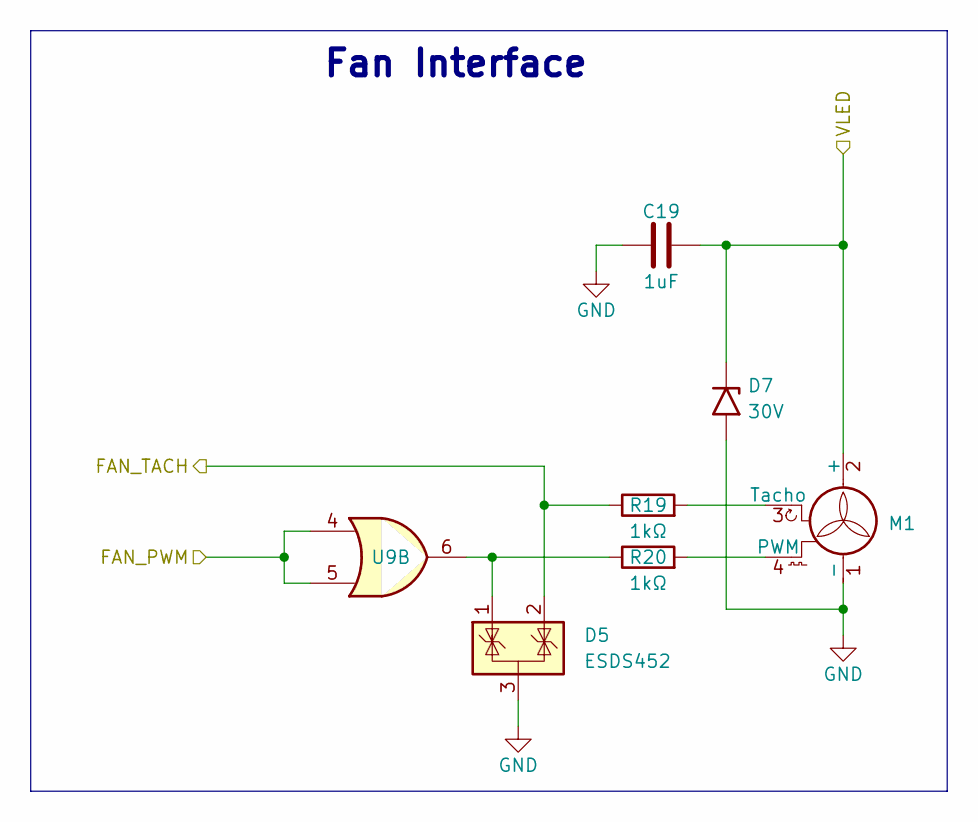
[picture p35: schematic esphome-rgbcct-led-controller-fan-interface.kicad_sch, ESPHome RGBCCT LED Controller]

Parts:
C19: 1uF; C_0402_1005Metric; Part Number GRM155R61H105KE05D
D5: ESDS452; SOT-23; Part Number ESDS452DBZR
D7: 30V; D_SMA; Part Number SMAJ30CA-13-F
M1: Fan_CPU_4pin; FanPinHeader_1x04_P2.54mm_Vertical; Part Number 47053-1000
R19, R20: 1kΩ; R_0402_1005Metric; Part Number CRCW04021K00FKED
U9: 74AHCT32; DHWQFN-14-1EP_2.5x3mm_P0.5mm_EP1x1.5mm; Part Number SN74AHCT32BQAR

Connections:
/ESP32/FAN_PWM: U9.4, U9.5; also elsewhere on the board
/ESP32/FAN_TACH: D5.2 (K), R19.1; also elsewhere on the board
/Fan Interface/VLED: C19.2, D7.1 (A1), M1.2 (+); also elsewhere on the board
GND: C19.1, D5.3 (A), D7.2 (A2), M1.1 (-); also elsewhere on the board
unnamed: D5.1 (K), R20.1, U9.6
unnamed: M1.4 (PWM), R20.2
unnamed: M1.3 (Tacho), R19.2

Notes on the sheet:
Fan Interface

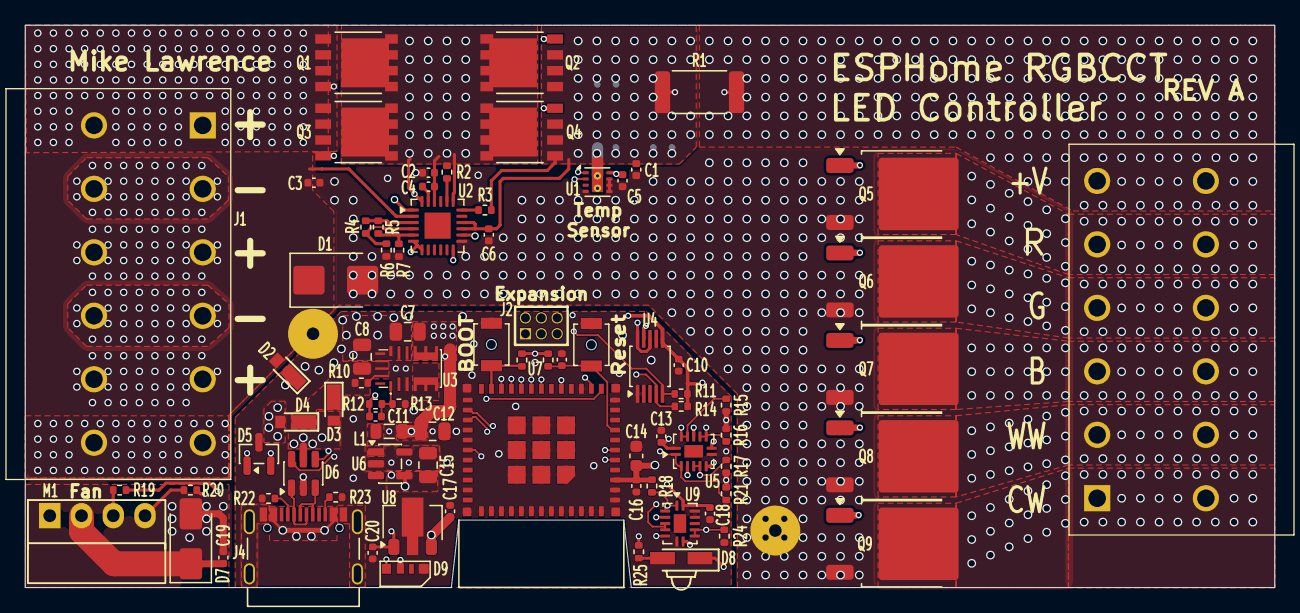
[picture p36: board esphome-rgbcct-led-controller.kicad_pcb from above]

Board: 6 copper layers, 100.0 x 45.0 mm, 83 parts (1 on the bottom side), 58 nets.

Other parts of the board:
TEXT1: OSHW-Logo_5.7x6mm_SilkScreen

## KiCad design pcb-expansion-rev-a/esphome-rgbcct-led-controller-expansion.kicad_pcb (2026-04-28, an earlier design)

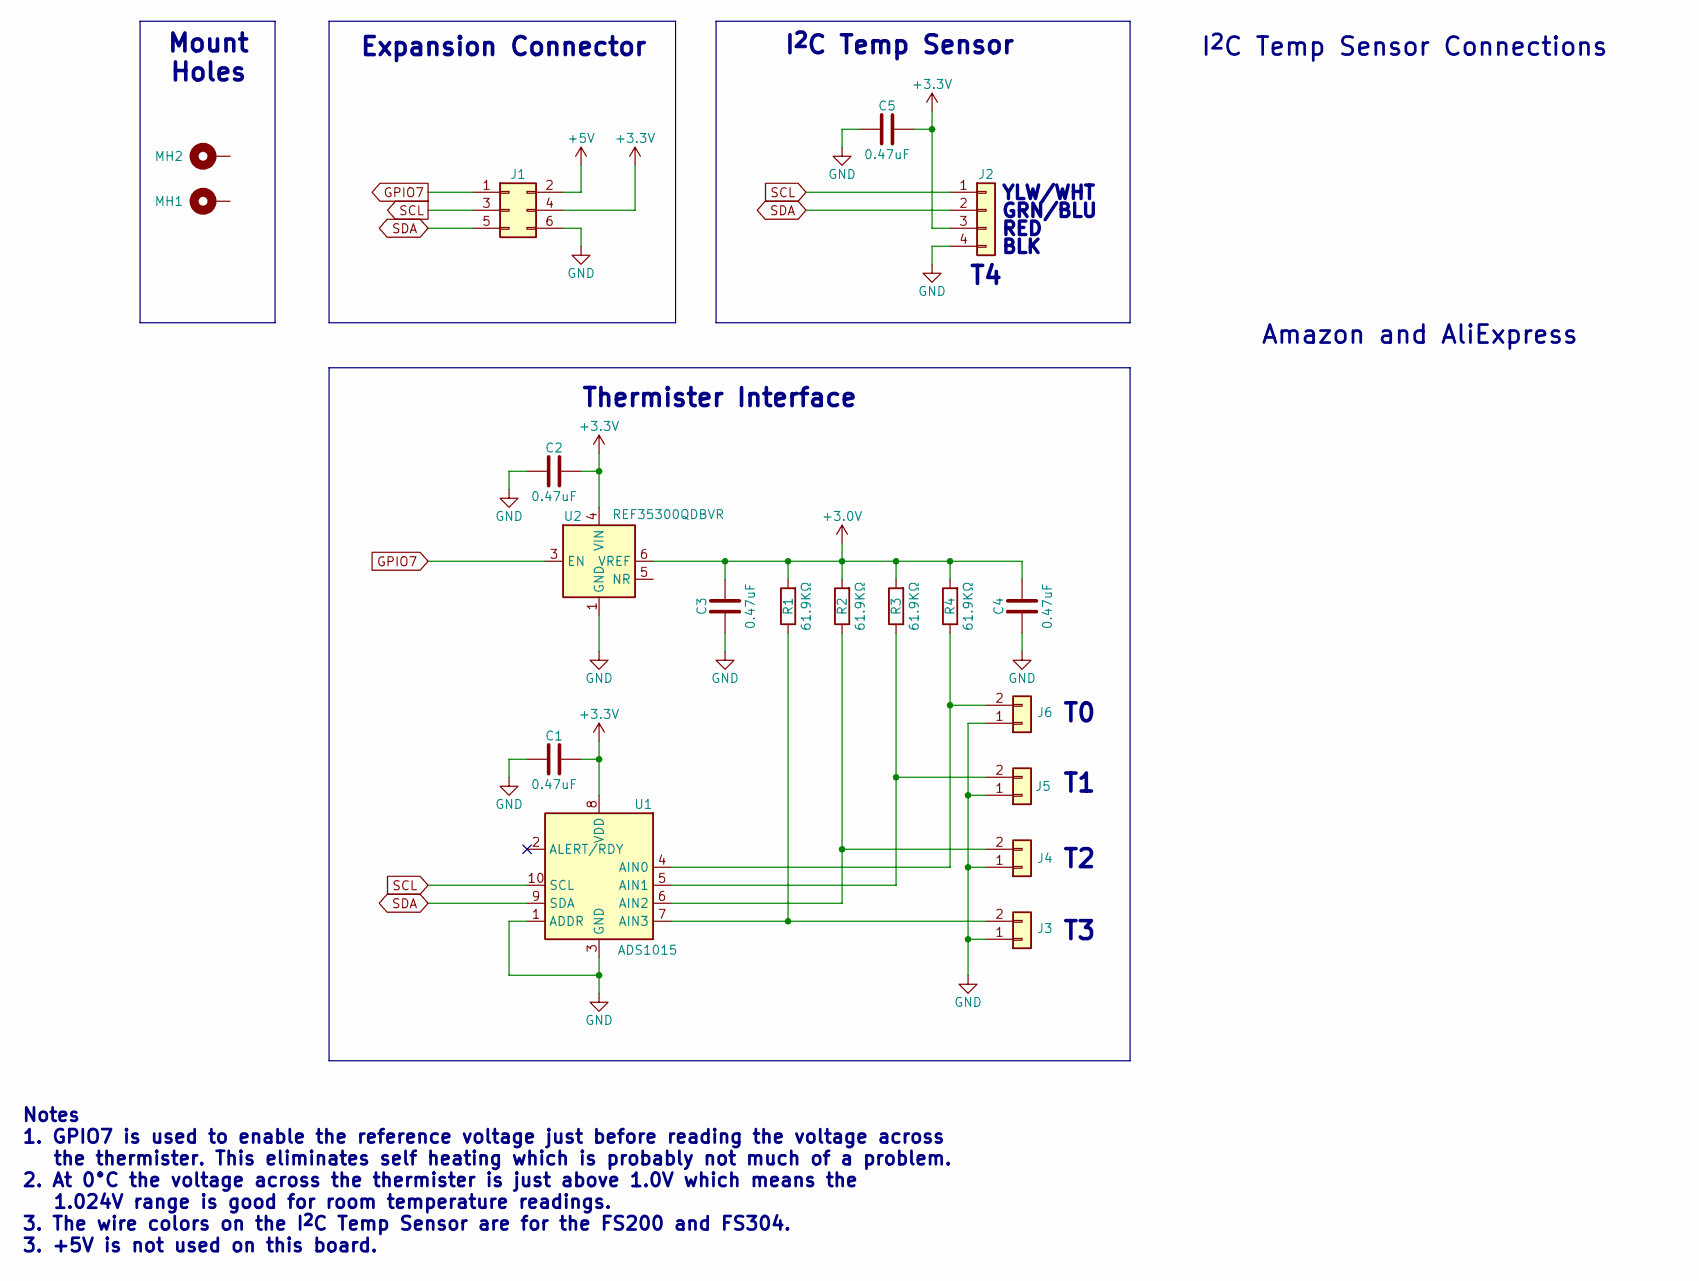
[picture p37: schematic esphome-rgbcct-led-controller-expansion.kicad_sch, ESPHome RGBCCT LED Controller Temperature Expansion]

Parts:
C1, C2, C3, C4, C5: 0.47uF; C_0805_2012Metric; Part Number CL21B474KAFNNNG; LCSC Part # C307331
J1: SAMTEC_SFMC-103-01-L-D; Part Number FTS-103-01-L-D
J2: Conn_01x04; JST_ZH_S4B-ZR-SM4A-TF_1x04-1MP_P1.50mm_Horizontal; Part Number S4B-ZR-SM4A-TF
J3, J4, J5, J6: Conn_01x02; JST_XH_S2B-XH-A_1x02_P2.50mm_Horizontal; Part Number S2B-XH-A(LF)(SN); LCSC Part # C157931
MH1, MH2: 97730606332R
R1, R2, R3, R4: 61.9KΩ; R_0805_2012Metric; Part Number RT0805BRD0761K9L; LCSC Part # C136977
U1: ADS1015; TSSOP-10_3x3mm_P0.5mm; Part Number ADS1015IDGSR
U2: REF35300QDBVR; SOT-23-6; Part Number REF35300QDBVR; LCSC Part # C6643299

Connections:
+3.0V: C3.1, C4.1, R1.2, R2.2, R3.2, R4.2, U2.6 (VREF)
+3.3V: C1.1, C2.2, C5.1, J1.4, J2.3, U1.8 (VDD), U2.4 (VIN)
+5V: J1.2
GND: C1.2, C2.1, C3.2, C4.2, C5.2, J1.6, J2.4, J3.1, J4.1, J5.1, J6.1, U1.1 (ADDR), U1.3 (GND), U2.1 (GND), U2.2 (GND)
GPIO7: J1.1, U2.3 (EN)
unnamed: J3.2, R1.1, U1.7 (AIN3)
unnamed: J4.2, R2.1, U1.6 (AIN2)
unnamed: J5.2, R3.1, U1.5 (AIN1)
unnamed: J6.2, R4.1, U1.4 (AIN0)
SCL: J1.3, J2.1, U1.10 (SCL)
SDA: J1.5, J2.2, U1.9 (SDA)

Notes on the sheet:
Mount Holes
Thermister Interface
BLK
RED
I^{2}C Temp Sensor
Amazon and AliExpress
GRN/BLU
Expansion Connector
YLW/WHT
I^{2}C Temp Sensor Connections
Notes 1. GPIO7 is used to enable the reference voltage just before reading the voltage across the thermister. This eliminates self heating which is probably not much of a problem. 2. At 0°C the voltage across the thermister is just above 1.0V which means the 1.024V range is good for room temperatur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

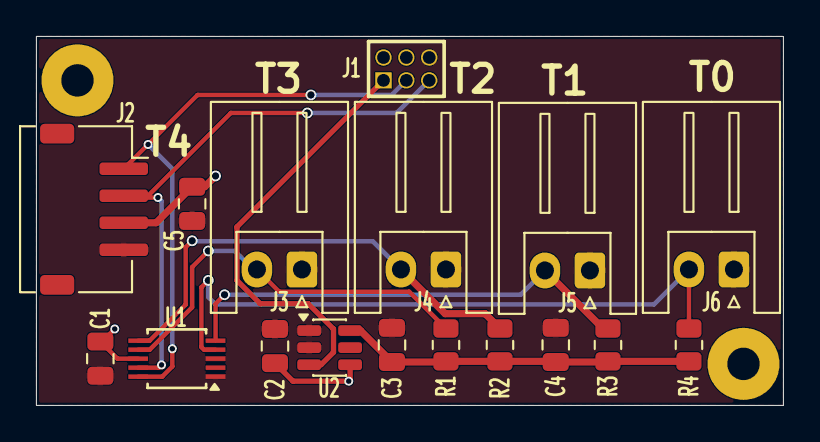
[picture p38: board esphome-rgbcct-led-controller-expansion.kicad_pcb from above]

Board: 2 copper layers, 41.5 x 20.5 mm, 20 parts (1 on the bottom side), 10 nets.

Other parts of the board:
TEXT1: OSHW-Logo_5.7x6mm_SilkScreen

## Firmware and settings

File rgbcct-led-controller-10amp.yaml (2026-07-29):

substitutions:
  # name must be unique across all factory builds in this project and 24 characters or less
  name: "rgbcct-led-controller-10amp"
  friendly_name: "RGBCCT LED Controller 10 Amp"

esphome:
  name: ${name}
  friendly_name: ${friendly_name}
  min_version: 2026.3.3
  # do not add mac suffix, name length will exceed 24-char max
  name_add_mac_suffix: false
  on_boot:
    priority: 600
    then:
      - light.turn_on:
          id: led_status
          effect: "Rainbow"

esp32:
  variant: ESP32C3
  framework:
    type: esp-idf

external_components:
  - source: github://mikelawrence/esphome-component-esp32-rmt-pwm
  - source: github://mikelawrence/esphome-component-rgbww-power-limited

# API is a requirement of the dashboard import
# Grab a key from https://esphome.io/components/api.html
api:
  reboot_timeout: 30min
  # encryption:
  # key:

# OTA is required for Over-the-Air updating
# If you enable web_server OTA, you should also enable authentication on the web server
#   otherwise anybody on your network could update your firmware
ota:
  # - platform: web_server
  - platform: esphome
    id: ota_esphome
    # password: !secret ota_password
  - platform: web_server
    id: ota_web_server

# Web Server
web_server:
  port: 80
  version: 3
  # auth:
  #   username: !secret web_server_username
  #   password: !secret web_server_password

  # WiFi is required
wifi:
  power_save_mode: none
  # ssid: !secret wifi_ssid
  # password: !secret wifi_password
  # use_address: xxx.xxx.xxx.xxx

# Allow user to provision WiFi credentials with USB port using Improv standard
improv_serial:

# Enable logging
logger:
  logs:
    pulse_counter: ERROR
    ads1115.sensor: ERROR
    ina2xx: ERROR

ads1115:
  address: 0x48
  continuous_mode: false

debug:
  update_interval: 60s

i2c:
  sda: GPIO1
  scl: GPIO8
  scan: true
  frequency: 400kHz

interval:
  - interval: 10s
    then:
      - output.turn_on: led_temp_ref_enable
      - delay: 10ms
      - component.update: t0_voltage
      - component.update: t1_voltage
      - component.update: t2_voltage
      - component.update: t3_voltage
      - output.turn_off: led_temp_ref_enable

time:
  - platform: homeassistant
    id: homeassistant_time

button:
  - platform: restart
    name: "Restart"

fan:
  - platform: speed
    output: fan_pwm
    name: "Fan"
    restore_mode: RESTORE_DEFAULT_ON

light:
  - platform: esp32_rmt_led_strip
    id: led_status
    rgb_order: RGB
    pin: GPIO2
    num_leds: 1
    rmt_symbols: 48
    chipset: ws2812
    effects:
      - addressable_rainbow:
          name: Rainbow
          speed: 10
          width: 50
  - platform: rgbww_power_limited
    id: rgbww_light_1
    output_id: rgbww_light_1_output
    name: "Light"
    red: output_red_int
    green: output_green_int
    blue: output_blue_int
    cold_white: output_cw_int
    warm_white: output_ww_int
    cold_white_color_temperature: 6500 K
    warm_white_color_temperature: 2800 K
    constant_brightness: false
    color_interlock: false
    restore_mode: RESTORE_DEFAULT_OFF
    gamma_correct: 1.0
    # Power limiting, Cap at 60% of total system power for this light
    max_power: 0.6

number:
  - platform: template
    name: "Max Power"
    id: max_power
    icon: "mdi:flash-alert"
    min_value: 1
    max_value: 100
    step: 1
    unit_of_measurement: "%"
    entity_category: CONFIG
    optimistic: true
    restore_value: true
    initial_value: 60
    set_action:
      - rgbww_power_limited.set_max_power:
          id: rgbww_light_1_output
          max_power: !lambda "return x / 100.0f;"
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

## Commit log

2026-04-08 Initial commit
    Far from fully tested
    [ESPHome LED RGBCCT LED Controller Stencil Base.step, ESPHome LED RGBCCT LED Controller Stencil Frame Thicker.step, ESPHome LED RGBCCT LED Controller Stencil Fr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]
2026-04-08 FIx minimum ESPHome version
    [rgbcct-led-controller-10a-esp32-c3.yaml, rgbcct-led-controller-5a-esp32-c3.yaml]
2026-04-08 Rename platform from power_limited_rgbww to rgbww_power_limited in light configuration
    [rgbcct-led-controller-10a-esp32-c3.yaml, rgbcct-led-controller-5a-esp32-c3.yaml]
2026-04-08 Change name from rgbcct to rgbww to reduce the length of the name.
    [rgbww-led-controller-10a-esp32-c3.factory.yaml, rgbww-led-controller-10a-esp32-c3.yaml, rgbww-led-controller-5a-esp32-c3.factory.yaml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]
2026-04-09 Remove unnecessary esp32-c3 from configurations
    [rgbww-led-controller-10a-esp32-c3.factory.yaml, rgbww-led-controller-10a.factory.yaml, rgbww-led-controller-10a.yaml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]
2026-04-09 Most recent updates to ESPHome configuration
    [rgbww-led-controller-10a.yaml, rgbww-led-controller-5a.yaml]
2026-04-09 Clarify fan pwm frequency.
2026-04-09 Eliminate overly verbose ina2xx logging
    [rgbww-led-controller-10a.yaml, rgbww-led-controller-5a.yaml]
2026-04-09 Add .yamllint and reformat yaml
    [rgbww-led-controller-10a.yaml, rgbww-led-controller-5a.yaml]
2026-04-10 Add esp32_rmt_pwm support and adjust fan PWM frequency settings
    [rgbww-led-controller-10a.yaml, rgbww-led-controller-5a.yaml]
2026-04-10 Refactor YAML configuration for web server and sensor filters Slow sensors down and reduce logging
    [rgbww-led-controller-10a.yaml, rgbww-led-controller-5a.yaml]
2026-04-10 Fix incorrect name
    [rgbww-led-controller-10a.yaml, rgbww-led-controller-5a.yaml]
2026-04-10 Import full config when using take over
    [rgbww-led-controller-10a.factory.yaml, rgbww-led-controller-5a.factory.yaml]
2026-04-11 Spell out Amp in friendly name
    [rgbww-led-controller-10a.factory.yaml, rgbww-led-controller-10a.yaml, rgbww-led-controller-5a.factory.yaml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]
2026-04-11 Remove Web Server OTA to improve security
    [rgbww-led-controller-10a.yaml, rgbww-led-controller-5a.yaml]
2026-04-11 Linting fix
    [rgbww-led-controller-10a.yaml, rgbww-led-controller-5a.yaml]
2026-04-11 Add paths filter for pull request trigger in CI workflow
2026-04-11 Test new github workflows, this introduces an error
    [rgbww-led-controller-5a.yaml]
2026-04-11 Fix error to see if workflows are still correct
    [rgbww-led-controller-5a.yaml]
2026-04-12 Split Expansion PCB in to Rev A and Rev B Rev A has JST ZR connector Rev B has screw terminal connectors These connectors as used by off-board i2c temperature and humidity sensor
    [bom.csv, designators.csv, esphome-rgbcct-led-controller-expansion-3d-model.step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]
2026-04-12 Fix Rev A Interactive BOM
2026-04-12 Update Expansion Rev A Schematic Add more details for connecting sensors
    [esphome-rgbcct-led-controller-expansion.kicad_sch]
2026-04-12 Update Rev B schematic pdf
2026-04-12 Update schematic image path in README
2026-04-27 Add Energy sensor with Wh units
    [esphome-rgbcct-led-controller-esp32.kicad_sch, esphome-rgbcct-led-controller-fan-interface.kicad_sch, esphome-rgbcct-led-controller-input-voltage.kicad_sch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]
2026-04-27 Update Kicad version
2026-04-27 YAML Linting fixes
    [rgbww-led-controller-10a.yaml, rgbww-led-controller-5a.yaml]
2026-04-27 Ignore Kicad .history files
2026-04-27 Fix source_id on copy components
    [rgbww-led-controller-10a.yaml, rgbww-led-controller-5a.yaml]
2026-04-27 Fix compile errors in ina2xx component
    [rgbww-led-controller-10a.yaml, rgbww-led-controller-5a.yaml]
2026-04-27 Fix missing power_id in energy sensor More YAML Linting fixes
    [rgbww-led-controller-10a.yaml, rgbww-led-controller-5a.yaml]
2026-04-27 Add ids
    [rgbww-led-controller-10a.yaml, rgbww-led-controller-5a.yaml]
2026-04-28 Finish updating to Kicad 10
    [esphome-rgbcct-led-controller-bom.csv, esphome-rgbcct-led-controller-expansion.kicad_pcb, esphome-rgbcct-led-controller-expansion.kicad_sch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]
2026-05-04 Fix link to PCB README in main README
2026-05-05 Add logger configuration with baud rate
    Hoping this will fix improv serial
    [rgbww-led-controller-5a.factory.yaml]
2026-07-23 Update external components
    [rgbww-led-controller-10a.yaml, rgbww-led-controller-5a.yaml]
2026-07-23 Sort external component list
    [rgbww-led-controller-10a.yaml, rgbww-led-controller-5a.yaml]
2026-07-23 OTA Performance improvements Turn off WiFi power_save_mode Turn off Bluetooth just before OTA update starts
    [rgbww-led-controller-10a.factory.yaml, rgbww-led-controller-10a.yaml, rgbww-led-controller-5a.factory.yaml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]
2026-07-27 Add OTA Web Update
    [rgbww-led-controller-10a.factory.yaml, rgbww-led-controller-10a.yaml, rgbww-led-controller-5a.factory.yaml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]
2026-07-27 Fix ref substitution in dashboard_import
    [rgbww-led-controller-10a.factory.yaml, rgbww-led-controller-5a.factory.yaml]
2026-07-27 More changes for OTA Performance improvements Remove Bluetooth Improv. Add Web Server OTA updates. Add HTTP Request OTA updates.
    [rgbww-led-controller-10a.factory.yaml, rgbww-led-controller-10a.yaml, rgbww-led-controller-5a.factory.yaml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]
2026-07-28 Change username to light
    [rgbww-led-controller-10a.factory.yaml, rgbww-led-controller-5a.factory.yaml]
2026-07-29 Rename config files This will allow a separate manifest.json file for older installs
    [rgbcct-led-controller-10amp.factory.yaml, rgbcct-led-controller-10amp.yaml, rgbcct-led-controller-5amp.factory.yaml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]
2026-07-29 Add WiFi signal strength sensor to 10 Amp and 5 Amp configurations
    [rgbcct-led-controller-10amp.yaml, rgbcct-led-controller-5amp.yaml]
2026-07-29 Yamllint fix
    [rgbcct-led-controller-5amp.yaml]
